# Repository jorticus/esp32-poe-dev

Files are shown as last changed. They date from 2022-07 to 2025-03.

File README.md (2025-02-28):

## ESP32 PoE Dev Board

A simple ESP32 ethernet + PoE dev board

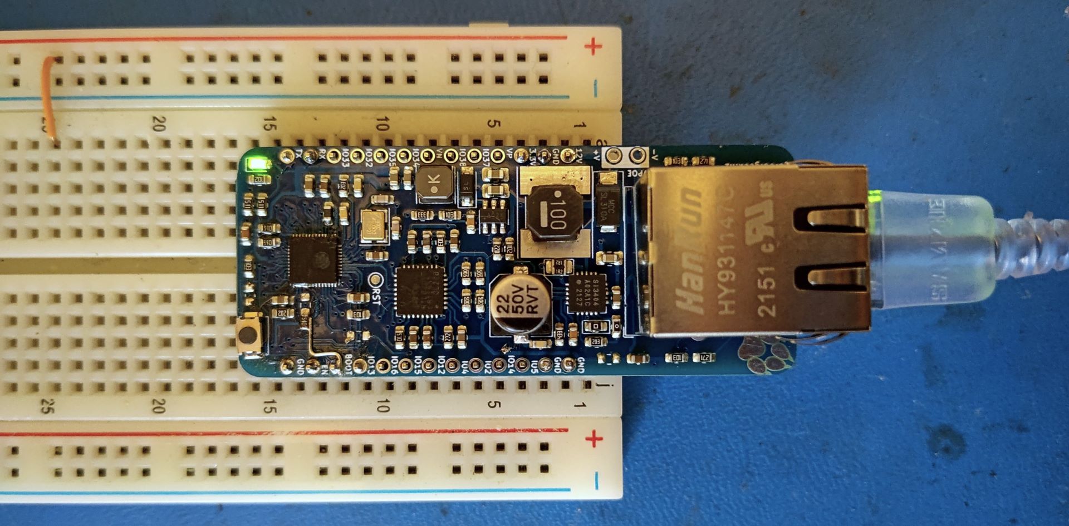
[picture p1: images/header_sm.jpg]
PoE Dev Board


WARNING: PoE is NOT ISOLATED! Be careful what you attach.

See [jared.geek.nz/esp32-poe-devboard](jared.geek.nz/esp32-poe-devboard) for the story.

## Usage

### ESPHome

```yaml
esp32:
  board: esp32dev

ethernet:
  type:     RTL8201
  mdc_pin:  GPIO23
  mdio_pin: GPIO18
  clk_mode: GPIO0_OUT
  phy_addr: 0

...
```

### Arduino

`main.cpp`
```cpp
void setup() {
    // WiFi antenna not available on this board
    WiFi.mode(WIFI_OFF); 

    ETH.begin();
    ETH.config();
}
```

`platformio.ini`
```ini
[platformio]

[env:esp32_poe]
platform  = espressif32
framework = arduino
board     = esp32_dev
build_flags = 
    -DETH_PHY_ADDR=0
    -DETH_PHY_MDC=23
    -DETH_PHY_MDIO=18
    -DETH_PHY_TYPE=ETH_PHY_RTL8201
    -DETH_CLK_MODE=ETH_CLOCK_GPIO0_OUT

```

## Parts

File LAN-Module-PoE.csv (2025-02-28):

Source: | P:\Electronics\LANModule\LAN-Module-PoE.kicad_sch
Date: | 4/12/2022 10:01:16 pm
Tool: | Eeschema (6.0.4)
Generator: | C:\Program Files\KiCad\6.0\bin\scripting\plugins/bom_csv_grouped_by_value.py
Component Count: | 102
Individual Components:
Item | Qty | Reference(s) | Value | LibPart | Footprint | Datasheet | Annotation | Dielectric | LCSC | Part | Part1 | Part2 | Range | Rating | Source | Spec | Tolerance
 |  | C1 | 100n | EspGateway-rescue:C_Small-device-EspGateway-rescue | Capacitor_SMD:C_0603_1608Metric |  |  |  | C113803 | CC0603KRX7R0BB104 |  |  | 100V |  |  | X5R
 |  | C2 | 100n | EspGateway-rescue:C_Small-device-EspGateway-rescue | Capacitor_SMD:C_0603_1608Metric
 |  | C3 | 100n | EspGateway-rescue:C_Small-device-EspGateway-rescue | Capacitor_SMD:C_0603_1608Metric |  |  |  |  |  |  |  | 50V |  |  | Y5V
 |  | C4 | 1u | EspGateway-rescue:C_Small-device-EspGateway-rescue | Capacitor_SMD:C_0805_2012Metric |  |  | X5R | C385977 | HMK212BC7105KGHTE |  |  | 100V
 |  | C5 | 10u | EspGateway-rescue:C_Small-device-EspGateway-rescue | Capacitor_SMD:C_0603_1608Metric |  |  |  |  |  |  |  | 3.3V
 |  | C6 | 1nF | EspGateway-rescue:C_Small-device-EspGateway-rescue | Capacitor_SMD:C_0603_1608Metric
 |  | C8 | 100n | EspGateway-rescue:C_Small-device-EspGateway-rescue | Resistor_SMD:R_0603_1608Metric
 |  | C9 | 100n | EspGateway-rescue:C_Small-device-EspGateway-rescue | Capacitor_SMD:C_0603_1608Metric
 |  | C10 | 1u | EspGateway-rescue:C_Small-device-EspGateway-rescue | Capacitor_SMD:C_0603_1608Metric |  |  |  |  |  |  |  | 3.3V
 |  | C11 | 1u | EspGateway-rescue:C_Small-device-EspGateway-rescue | Capacitor_SMD:C_0603_1608Metric |  |  |  |  |  |  |  | 3.3V
 |  | C12 | 22p | EspGateway-rescue:C_Small-device-EspGateway-rescue | Capacitor_SMD:C_0603_1608Metric
 |  | C13 | 22p | EspGateway-rescue:C_Small-device-EspGateway-rescue | Capacitor_SMD:C_0603_1608Metric
 |  | C14 | 4.7u | EspGateway-rescue:C_Small-device-EspGateway-rescue | Capacitor_SMD:C_0603_1608Metric |  |  |  |  |  |  |  | 3.3V
 |  | C15 | 3.3n | EspGateway-rescue:C_Small-device-EspGateway-rescue | Capacitor_SMD:C_0603_1608Metric
 |  | C16 | 10n | EspGateway-rescue:C_Small-device-EspGateway-rescue | Capacitor_SMD:C_0603_1608Metric
 |  | C17 | 100n | EspGateway-rescue:C_Small-device-EspGateway-rescue | Capacitor_SMD:C_0603_1608Metric |  |  |  |  |  |  |  | 12V |  |  | X5R
 |  | C18 | 2.2u | EspGateway-rescue:C_Small-device-EspGateway-rescue | Capacitor_SMD:C_0805_2012Metric |  |  | X5R | C268016 | UMK107BBJ225KA |  |  | 50V
 |  | C19 | 100n | EspGateway-rescue:C_Small-device-EspGateway-rescue | Capacitor_SMD:C_0603_1608Metric
 |  | C20 | 100n | EspGateway-rescue:C_Small-device-EspGateway-rescue | Capacitor_SMD:C_0603_1608Metric |  |  |  |  |  |  |  | 5V
 |  | C21 | 1u | EspGateway-rescue:C_Small-device-EspGateway-rescue | Capacitor_SMD:C_0603_1608Metric |  |  |  |  |  |  |  | 16V |  |  | X5R
 |  | C22 | 100n | EspGateway-rescue:C_Small-device-EspGateway-rescue | Resistor_SMD:R_0603_1608Metric |  |  |  |  |  |  |  |  |  |  | X5R
 |  | C23 | 100n | EspGateway-rescue:C_Small-device-EspGateway-rescue | Capacitor_SMD:C_0603_1608Metric |  |  |  |  |  |  |  |  |  |  | X5R
 |  | C24 | 100n | EspGateway-rescue:C_Small-device-EspGateway-rescue | Capacitor_SMD:C_0603_1608Metric |  |  |  |  |  |  |  |  |  |  | X5R
 |  | C25 | 100n | EspGateway-rescue:C_Small-device-EspGateway-rescue | Capacitor_SMD:C_0603_1608Metric |  |  |  |  |  |  |  |  |  |  | X5R
 |  | C26 | 100n | EspGateway-rescue:C_Small-device-EspGateway-rescue | Capacitor_SMD:C_0603_1608Metric |  |  |  |  |  |  |  |  |  |  | X5R
 |  | C27 | 22u | Device:C_Polarized_Small | Capacitor_SMD:C_Elec_6.3x5.4 | ~ |  |  | C487431 | VKMC1002A220MV |  |  | 100V
 |  | C29 | 2.2u | EspGateway-rescue:C_Small-device-EspGateway-rescue | Capacitor_SMD:C_0805_2012Metric |  |  | X5R | C268016 | UMK107BBJ225KA |  |  | 50V
 |  | D1 | SL310A | Device:D_Small | Diode_SMD:D_SMA | ~
 |  | D2 | PMEG6020ER,115 | Device:D_Small | Diode_SMD:D_SOD-123 | ~
 |  | D3 | Green | Device:LED_Small_Filled | LED_SMD:LED_0603_1608Metric | ~
 |  | J1 | HY931147C | Visclib:HY931147C | Connector_RJ:RJ45_Wuerth_7499111446_Horizontal |  |  |  | C12074 | LCSC:C12074 |  |  |  |  | https://lcsc.com/product-detail/Ethernet-Connectors-Modular-Connectors-RJ45-RJ11_HANRUN-Zhongshan-HanRun-Elec-HR911105A_C12074.html
 |  | J2 | ProtoCastellatedHeader | Visclib:ProtoCastellatedHeader | Visclib:ProtoHeader_65mil
 |  | J3 | ProtoCastellatedHeader | Visclib:ProtoCastellatedHeader | Visclib:ProtoHeader_65mil
 |  | J4 | ProtoCastellatedHeader | Visclib:ProtoCastellatedHeader | Visclib:ProtoHeader_65mil
 |  | J5 | ProtoCastellatedHeader | Visclib:ProtoCastellatedHeader | Visclib:ProtoHeader_65mil
 |  | J6 | ProtoCastellatedHeader | Visclib:ProtoCastellatedHeader | Visclib:ProtoHeader_65mil
 |  | J7 | ProtoCastellatedHeader | Visclib:ProtoCastellatedHeader | Visclib:ProtoHeader_65mil
 |  | J8 | ProtoCastellatedHeader | Visclib:ProtoCastellatedHeader | Visclib:ProtoHeader_65mil
 |  | J9 | ProtoCastellatedHeader | Visclib:ProtoCastellatedHeader | Visclib:ProtoHeader_65mil
 |  | J10 | ProtoCastellatedHeader | Visclib:ProtoCastellatedHeader | Visclib:ProtoHeader_65mil
 |  | J11 | ProtoCastellatedHeader | Visclib:ProtoCastellatedHeader | Visclib:ProtoHeader_65mil
 |  | J12 | ProtoCastellatedHeader | Visclib:ProtoCastellatedHeader | Visclib:ProtoHeader_65mil
 |  | J13 | ProtoCastellatedHeader | Visclib:ProtoCastellatedHeader | Visclib:ProtoHeader_65mil
 |  | J14 | ProtoCastellatedHeader | Visclib:ProtoCastellatedHeader | Visclib:ProtoHeader_65mil
 |  | J15 | ProtoCastellatedHeader | Visclib:ProtoCastellatedHeader | Visclib:ProtoHeader_65mil
 |  | J16 | ProtoCastellatedHeader | Visclib:ProtoCastellatedHeader | Visclib:ProtoHeader_65mil
 |  | J17 | ProtoCastellatedHeader | Visclib:ProtoCastellatedHeader | Visclib:ProtoHeader_65mil
 |  | J18 | ProtoCastellatedHeader | Visclib:ProtoCastellatedHeader | Visclib:ProtoHeader_65mil
 |  | J19 | ProtoCastellatedHeader | Visclib:ProtoCastellatedHeader | Visclib:ProtoHeader_65mil
 |  | J20 | ProtoCastellatedHeader | Visclib:ProtoCastellatedHeader | Visclib:ProtoHeader_65mil
 |  | J21 | ProtoCastellatedHeader | Visclib:ProtoCastellatedHeader | Visclib:ProtoHeader_65mil
 |  | J22 | ProtoCastellatedHeader | Visclib:ProtoCastellatedHeader | Visclib:ProtoHeader_65mil
 |  | J23 | ProtoCastellatedHeader | Visclib:ProtoCastellatedHeader | Visclib:ProtoHeader_65mil
 |  | J24 | ProtoCastellatedHeader | Visclib:ProtoCastellatedHeader | Visclib:ProtoHeader_65mil
 |  | J25 | ProtoCastellatedHeader | Visclib:ProtoCastellatedHeader | Visclib:ProtoHeader_65mil
 |  | J26 | ProtoCastellatedHeader | Visclib:ProtoCastellatedHeader | Visclib:ProtoHeader_65mil
 |  | J27 | ProtoCastellatedHeader | Visclib:ProtoCastellatedHeader | Visclib:ProtoHeader_65mil
 |  | J28 | ProtoCastellatedHeader | Visclib:ProtoCastellatedHeader | Visclib:ProtoHeader_65mil
 |  | J29 | ProtoCastellatedHeader | Visclib:ProtoCastellatedHeader | Visclib:ProtoHeader_65mil
 |  | L1 | FB 600R@100MHz 1.3A | EspGateway-rescue:L_Small-device-EspGateway-rescue | Resistor_SMD:R_0603_1608Metric |  |  |  | C85833 | BLM18KG601SN1D
 |  | L2 | 10uH 1A | Device:L_Small | Inductor_SMD:L_Taiyo-Yuden_NR-40xx | ~ |  |  | C222882 | NRS4018T100MDGJ
 |  | L3 | FB 600R@100MHz 1.3A | EspGateway-rescue:L_Small-device-EspGateway-rescue | Resistor_SMD:R_0603_1608Metric |  |  |  | C85833 | BLM18KG601SN1D
 |  | L4 | 33uH | Device:L_Small | Inductor_SMD:L_Taiyo-Yuden_NR-80xx_HandSoldering | ~ |  |  | C2681905 | YNR8065-330M |  |  |  | 1.2A
 |  | LOGO1 | Logo | Visclib:Logo | Visclib:wolfpaw-0.3
 |  | R1 | 10k | EspGateway-rescue:R_Small_US-device-EspGateway-rescue | Resistor_SMD:R_0603_1608Metric
 |  | R2 | 2k | EspGateway-rescue:R_Small_US-device-EspGateway-rescue | Resistor_SMD:R_0603_1608Metric
 |  | R3 | 20K | EspGateway-rescue:R_Small_US-device-EspGateway-rescue | Resistor_SMD:R_0603_1608Metric
 |  | R4 | 499R | EspGateway-rescue:R_Small_US-device-EspGateway-rescue | Resistor_SMD:R_0603_1608Metric
 |  | R6 | 24.3k 1% | EspGateway-rescue:R_Small_US-device-EspGateway-rescue | Resistor_SMD:R_0603_1608Metric |  |  |  | C2930079
 |  | R7 | DNP | EspGateway-rescue:R_Small_US-device-EspGateway-rescue | Resistor_SMD:R_0603_1608Metric
 |  | R8 | 2.49k 1% | EspGateway-rescue:R_Small_US-device-EspGateway-rescue | Resistor_SMD:R_0603_1608Metric |  |  |  | C2930072
 |  | R9 | 10k | EspGateway-rescue:R_Small_US-device-EspGateway-rescue | Resistor_SMD:R_0603_1608Metric
 |  | R10 | 10k | EspGateway-rescue:R_Small_US-device-EspGateway-rescue | Resistor_SMD:R_0603_1608Metric
 |  | R11 | 10k | EspGateway-rescue:R_Small_US-device-EspGateway-rescue | Resistor_SMD:R_0603_1608Metric
 |  | R12 | 10k | EspGateway-rescue:R_Small_US-device-EspGateway-rescue | Resistor_SMD:R_0603_1608Metric
 |  | R13 | 50R 1% | EspGateway-rescue:R_Small_US-device-EspGateway-rescue | Resistor_SMD:R_0603_1608Metric |  |  |  | C2759402 |  |  |  |  |  |  |  | 1%
 |  | R14 | 50R 1% | EspGateway-rescue:R_Small_US-device-EspGateway-rescue | Resistor_SMD:R_0603_1608Metric |  |  |  |  |  |  |  |  |  |  |  | 1%
 |  | R15 | 240R | EspGateway-rescue:R_Small_US-device-EspGateway-rescue | Resistor_SMD:R_0603_1608Metric
 |  | R16 | 240R | EspGateway-rescue:R_Small_US-device-EspGateway-rescue | Resistor_SMD:R_0603_1608Metric
 |  | R17 | 50R 1% | EspGateway-rescue:R_Small_US-device-EspGateway-rescue | Resistor_SMD:R_0603_1608Metric |  |  |  |  |  |  |  |  |  |  |  | 1%
 |  | R18 | 50R 1% | EspGateway-rescue:R_Small_US-device-EspGateway-rescue | Resistor_SMD:R_0603_1608Metric |  |  |  |  |  |  |  |  |  |  | Tolerance
 |  | R19 | 0R | EspGateway-rescue:R_Small_US-device-EspGateway-rescue | Resistor_SMD:R_0603_1608Metric
 |  | R20 | 0.62R | EspGateway-rescue:R_Small_US-device-EspGateway-rescue | Resistor_SMD:R_0805_2012Metric |  |  |  | C2930222 |  |  |  |  |  |  | 1/10W
 |  | R21 | 47k | EspGateway-rescue:R_Small_US-device-EspGateway-rescue | Resistor_SMD:R_0603_1608Metric
 |  | R22 | 499R | EspGateway-rescue:R_Small_US-device-EspGateway-rescue | Resistor_SMD:R_0603_1608Metric
 |  | R23 | 1k | EspGateway-rescue:R_Small_US-device-EspGateway-rescue | Resistor_SMD:R_0603_1608Metric
 |  | R24 | 8.2k | EspGateway-rescue:R_Small_US-device-EspGateway-rescue | Resistor_SMD:R_0603_1608Metric
 |  | R25 | 0R | EspGateway-rescue:R_Small_US-device-EspGateway-rescue | Resistor_SMD:R_0603_1608Metric |  | DNP
 |  | R26 | 33k 1% | EspGateway-rescue:R_Small_US-device-EspGateway-rescue | Resistor_SMD:R_0603_1608Metric
 |  | R27 | 10k 1% | EspGateway-rescue:R_Small_US-device-EspGateway-rescue | Resistor_SMD:R_0603_1608Metric
 |  | R28 | 1k | EspGateway-rescue:R_Small_US-device-EspGateway-rescue | Resistor_SMD:R_0603_1608Metric
 |  | R29 | 50R | EspGateway-rescue:R_Small_US-device-EspGateway-rescue | Resistor_SMD:R_0603_1608Metric
 |  | R30 | 50R | EspGateway-rescue:R_Small_US-device-EspGateway-rescue | Resistor_SMD:R_0603_1608Metric
 |  | R31 | 50R | EspGateway-rescue:R_Small_US-device-EspGateway-rescue | Resistor_SMD:R_0603_1608Metric
 |  | R32 | 50R | EspGateway-rescue:R_Small_US-device-EspGateway-rescue | Resistor_SMD:R_0603_1608Metric
 |  | SW1 | RESET | Switch:SW_Push | Button_Switch_SMD:SW_Push_SPST_NO_Alps_SKRK | ~
 |  | TP1 | TP | visclib:TP | Visclib:TP-1MM
 |  | U1 | ESP32-U4WDH | Visclib:ESP32-D0WD | Package_DFN_QFN:QFN-48-1EP_5x5mm_P0.35mm_EP3.7x3.7mm_ThermalVias |  |  |  | C529586/C3013932 |  | LCSC:C529586 | LCSC:C967021
 |  | U2 | Si3404 | Visclib:Si3404 | Package_DFN_QFN:QFN-20-1EP_4x4mm_P0.5mm_EP2.6x2.6mm |  |  |  | C461934 | LCSC:C461934
 |  | U3 | LV2842XLVDDCR | Visclib:LV2841 | Package_TO_SOT_SMD:SOT-23-6 |  |  |  | C225807
 |  | U4 | RTL8201F | EspGateway-rescue:RTL8201F-visclib-EspGateway-rescue | Package_DFN_QFN:QFN-32-1EP_5x5mm_P0.5mm_EP3.1x3.1mm |  |  |  | C2763557/C45044 |  |  |  |  |  | https://lcsc.com/product-detail/Ethernet-ICs_Realtek-Semicon-RTL8201FI-VC-CG_C2763557.html
 |  | Y1 | 40MHz | EspGateway-rescue:Crystal_GND24_Small-device-EspGateway-rescue | Crystal:Crystal_SMD_3225-4Pin_3.2x2.5mm |  |  |  | C9010/C555624 |  |  |  |  |  |  | ±10ppm
Collated Components:
Item | Qty | Reference(s) | Value | LibPart | Footprint | Datasheet | Annotation | Dielectric | LCSC | Part | Part1 | Part2 | Range | Rating | Source | Spec | Tolerance
1 | 11 | C1, C2, C3, C9, C17, C19, C20, C23, C24, C25, C26 | 100n | EspGateway-rescue:C_Small-device-EspGateway-rescue | Capacitor_SMD:C_0603_1608Metric |  |  |  | C113803 | CC0603KRX7R0BB104 |  |  | 100V |  |  | X5R
2 | 1 | C4 | 1u | EspGateway-rescue:C_Small-device-EspGateway-rescue | Capacitor_SMD:C_0805_2012Metric |  |  | X5R | C385977 | HMK212BC7105KGHTE |  |  | 100V
3 | 1 | C5 | 10u | EspGateway-rescue:C_Small-device-EspGateway-rescue | Capacitor_SMD:C_0603_1608Metric |  |  |  |  |  |  |  | 3.3V
4 | 1 | C6 | 1nF | EspGateway-rescue:C_Small-device-EspGateway-rescue | Capacitor_SMD:C_0603_1608Metric
5 | 2 | C8, C22 | 100n | EspGateway-rescue:C_Small-device-EspGateway-rescue | Resistor_SMD:R_0603_1608Metric |  |  |  |  |  |  |  |  |  |  | X5R
6 | 3 | C10, C11, C21 | 1u | EspGateway-rescue:C_Small-device-EspGateway-rescue | Capacitor_SMD:C_0603_1608Metric |  |  |  |  |  |  |  | 3.3V |  |  | X5R
7 | 2 | C12, C13 | 22p | EspGateway-rescue:C_Small-device-EspGateway-rescue | Capacitor_SMD:C_0603_1608Metric
8 | 1 | C14 | 4.7u | EspGateway-rescue:C_Small-device-EspGateway-rescue | Capacitor_SMD:C_0603_1608Metric |  |  |  |  |  |  |  | 3.3V
9 | 1 | C15 | 3.3n | EspGateway-rescue:C_Small-device-EspGateway-rescue | Capacitor_SMD:C_0603_1608Metric
10 | 1 | C16 | 10n | EspGateway-rescue:C_Small-device-EspGateway-rescue | Capacitor_SMD:C_0603_1608Metric
11 | 2 | C18, C29 | 2.2u | EspGateway-rescue:C_Small-device-EspGateway-rescue | Capacitor_SMD:C_0805_2012Metric |  |  | X5R | C268016 | UMK107BBJ225KA |  |  | 50V
12 | 1 | C27 | 22u | Device:C_Polarized_Small | Capacitor_SMD:C_Elec_6.3x5.4 | ~ |  |  | C487431 | VKMC1002A220MV |  |  | 100V
13 | 1 | D1 | SL310A | Device:D_Small | Diode_SMD:D_SMA | ~
14 | 1 | D2 | PMEG6020ER,115 | Device:D_Small | Diode_SMD:D_SOD-123 | ~
15 | 1 | D3 | Green | Device:LED_Small_Filled | LED_SMD:LED_0603_1608Metric | ~
16 | 1 | J1 | HY931147C | Visclib:HY931147C | Connector_RJ:RJ45_Wuerth_7499111446_Horizontal |  |  |  | C12074 | LCSC:C12074 |  |  |  |  | https://lcsc.com/product-detail/Ethernet-Connectors-Modular-Connectors-RJ45-RJ11_HANRUN-Zhongshan-HanRun-Elec-HR911105A_C12074.html
17 | 28 | J2, J3, J4, J5, J6, J7, J8, J9, J10, J11, J12, J13, J14, J15, J16, J17, J18, J19, J20, J21, J22, J23, J24, J25, J26, J27, J28, J29 | ProtoCastellatedHeader | Visclib:ProtoCastellatedHeader | Visclib:ProtoHeader_65mil
18 | 2 | L1, L3 | FB 600R@100MHz 1.3A | EspGateway-rescue:L_Small-device-EspGateway-rescue | Resistor_SMD:R_0603_1608Metric |  |  |  | C85833 | BLM18KG601SN1D
19 | 1 | L2 | 10uH 1A | Device:L_Small | Inductor_SMD:L_Taiyo-Yuden_NR-40xx | ~ |  |  | C222882 | NRS4018T100MDGJ
20 | 1 | L4 | 33uH | Device:L_Small | Inductor_SMD:L_Taiyo-Yuden_NR-80xx_HandSoldering | ~ |  |  | C2681905 | YNR8065-330M |  |  |  | 1.2A
21 | 1 | LOGO1 | Logo | Visclib:Logo | Visclib:wolfpaw-0.3
22 | 5 | R1, R9, R10, R11, R12 | 10k | EspGateway-rescue:R_Small_US-device-EspGateway-rescue | Resistor_SMD:R_0603_1608Metric
23 | 1 | R2 | 2k | EspGateway-rescue:R_Small_US-device-EspGateway-rescue | Resistor_SMD:R_0603_1608Metric
24 | 1 | R3 | 20K | EspGateway-rescue:R_Small_US-device-EspGateway-rescue | Resistor_SMD:R_0603_1608Metric
25 | 2 | R4, R22 | 499R | EspGateway-rescue:R_Small_US-device-EspGateway-rescue | Resistor_SMD:R_0603_1608Metric
26 | 1 | R6 | 24.3k 1% | EspGateway-rescue:R_Small_US-device-EspGateway-rescue | Resistor_SMD:R_0603_1608Metric |  |  |  | C2930079
27 | 1 | R7 | DNP | EspGateway-rescue:R_Small_US-device-EspGateway-rescue | Resistor_SMD:R_0603_1608Metric
28 | 1 | R8 | 2.49k 1% | EspGateway-rescue:R_Small_US-device-EspGateway-rescue | Resistor_SMD:R_0603_1608Metric |  |  |  | C2930072
29 | 4 | R13, R14, R17, R18 | 50R 1% | EspGateway-rescue:R_Small_US-device-EspGateway-rescue | Resistor_SMD:R_0603_1608Metric |  |  |  | C2759402 |  |  |  |  |  |  | Tolerance | 1%
30 | 2 | R15, R16 | 240R | EspGateway-rescue:R_Small_US-device-EspGateway-rescue | Resistor_SMD:R_0603_1608Metric
31 | 2 | R19, R25 | 0R | EspGateway-rescue:R_Small_US-device-EspGateway-rescue | Resistor_SMD:R_0603_1608Metric |  | DNP
32 | 1 | R20 | 0.62R | EspGateway-rescue:R_Small_US-device-EspGateway-rescue | Resistor_SMD:R_0805_2012Metric |  |  |  | C2930222 |  |  |  |  |  |  | 1/10W
33 | 1 | R21 | 47k | EspGateway-rescue:R_Small_US-device-EspGateway-rescue | Resistor_SMD:R_0603_1608Metric
34 | 2 | R23, R28 | 1k | EspGateway-rescue:R_Small_US-device-EspGateway-rescue | Resistor_SMD:R_0603_1608Metric
35 | 1 | R24 | 8.2k | EspGateway-rescue:R_Small_US-device-EspGateway-rescue | Resistor_SMD:R_0603_1608Metric
36 | 1 | R26 | 33k 1% | EspGateway-rescue:R_Small_US-device-EspGateway-rescue | Resistor_SMD:R_0603_1608Metric
37 | 1 | R27 | 10k 1% | EspGateway-rescue:R_Small_US-device-EspGateway-rescue | Resistor_SMD:R_0603_1608Metric
38 | 4 | R29, R30, R31, R32 | 50R | EspGateway-rescue:R_Small_US-device-EspGateway-rescue | Resistor_SMD:R_0603_1608Metric
39 | 1 | SW1 | RESET | Switch:SW_Push | Button_Switch_SMD:SW_Push_SPST_NO_Alps_SKRK | ~
40 | 1 | TP1 | TP | visclib:TP | Visclib:TP-1MM
41 | 1 | U1 | ESP32-U4WDH | Visclib:ESP32-D0WD | Package_DFN_QFN:QFN-48-1EP_5x5mm_P0.35mm_EP3.7x3.7mm_ThermalVias |  |  |  | C529586/C3013932 |  | LCSC:C529586 | LCSC:C967021
42 | 1 | U2 | Si3404 | Visclib:Si3404 | Package_DFN_QFN:QFN-20-1EP_4x4mm_P0.5mm_EP2.6x2.6mm |  |  |  | C461934 | LCSC:C461934
43 | 1 | U3 | LV2842XLVDDCR | Visclib:LV2841 | Package_TO_SOT_SMD:SOT-23-6 |  |  |  | C225807
44 | 1 | U4 | RTL8201F | EspGateway-rescue:RTL8201F-visclib-EspGateway-rescue | Package_DFN_QFN:QFN-32-1EP_5x5mm_P0.5mm_EP3.1x3.1mm |  |  |  | C2763557/C45044 |  |  |  |  |  | https://lcsc.com/product-detail/Ethernet-ICs_Realtek-Semicon-RTL8201FI-VC-CG_C2763557.html
45 | 1 | Y1 | 40MHz | EspGateway-rescue:Crystal_GND24_Small-device-EspGateway-rescue | Crystal:Crystal_SMD_3225-4Pin_3.2x2.5mm |  |  |  | C9010/C555624 |  |  |  |  |  |  | ±10ppm

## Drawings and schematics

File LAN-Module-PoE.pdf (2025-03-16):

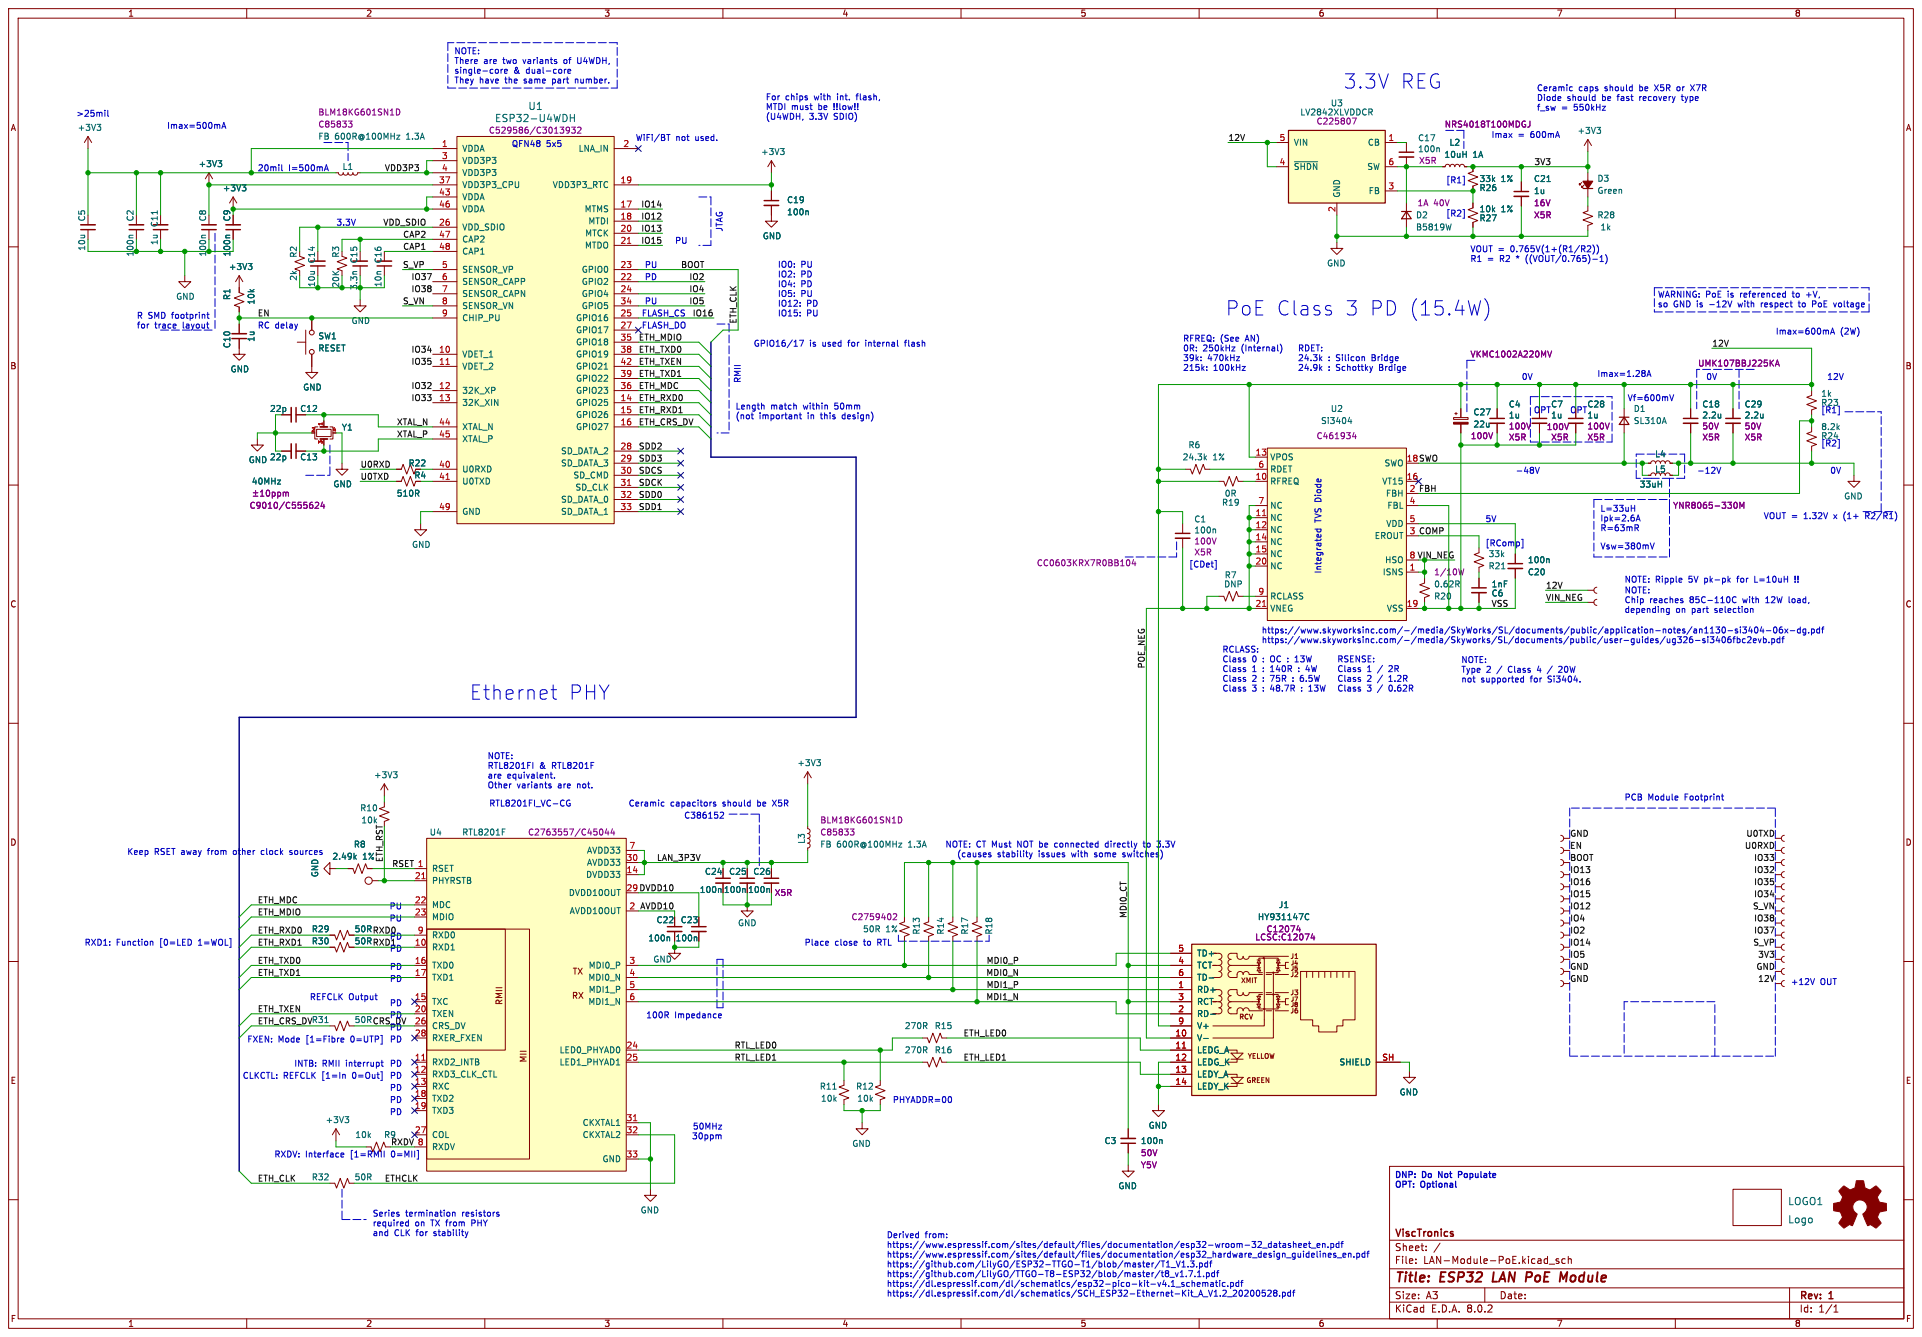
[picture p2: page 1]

Diode should be fast recovery type
f_sw = 550kHz

For chips with int. flash, MTDI must be !!low!! (U4WDH, 3.3V SDIO)

Place close to RTL RMII

VOUT = 1.32V x (1+ R2/R1) 0V RC delay R SMD footprint
for trace layout

https://www.skyworksinc.com/-/media/Skyworks/SL/documents/public/user-guides/ug326-si3406fbc2evb.pdf Integrated TVS Diode

https://www.skyworksinc.com/-/media/SkyWorks/SL/documents/public/application-notes/an1130-si3404-06x-dg.pdf

DNP: Do Not Populate OPT: Optional REFCLK Output

and CLK for stability

Derived from: https://www.espressif.com/sites/default/files/documentation/esp32-wroom-32_datasheet_en.pdf

https://www.espressif.com/sites/default/files/documentation/esp32_hardware_design_guidelines_en.pdf
https://github.com/LilyGO/ESP32-TTGO-T1/blob/master/T1_V1.3.pdf
https://github.com/LilyGO/TTGO-T8-ESP32/blob/master/t8_v1.7.1.pdf
https://dl.espressif.com/dl/schematics/esp32-pico-kit-v4.1_schematic.pdf
https://dl.espressif.com/dl/schematics/SCH_ESP32-Ethernet-Kit_A_V1.2_20200528.pdf

Id: 1/1 Title: ESP32 LAN PoE Module

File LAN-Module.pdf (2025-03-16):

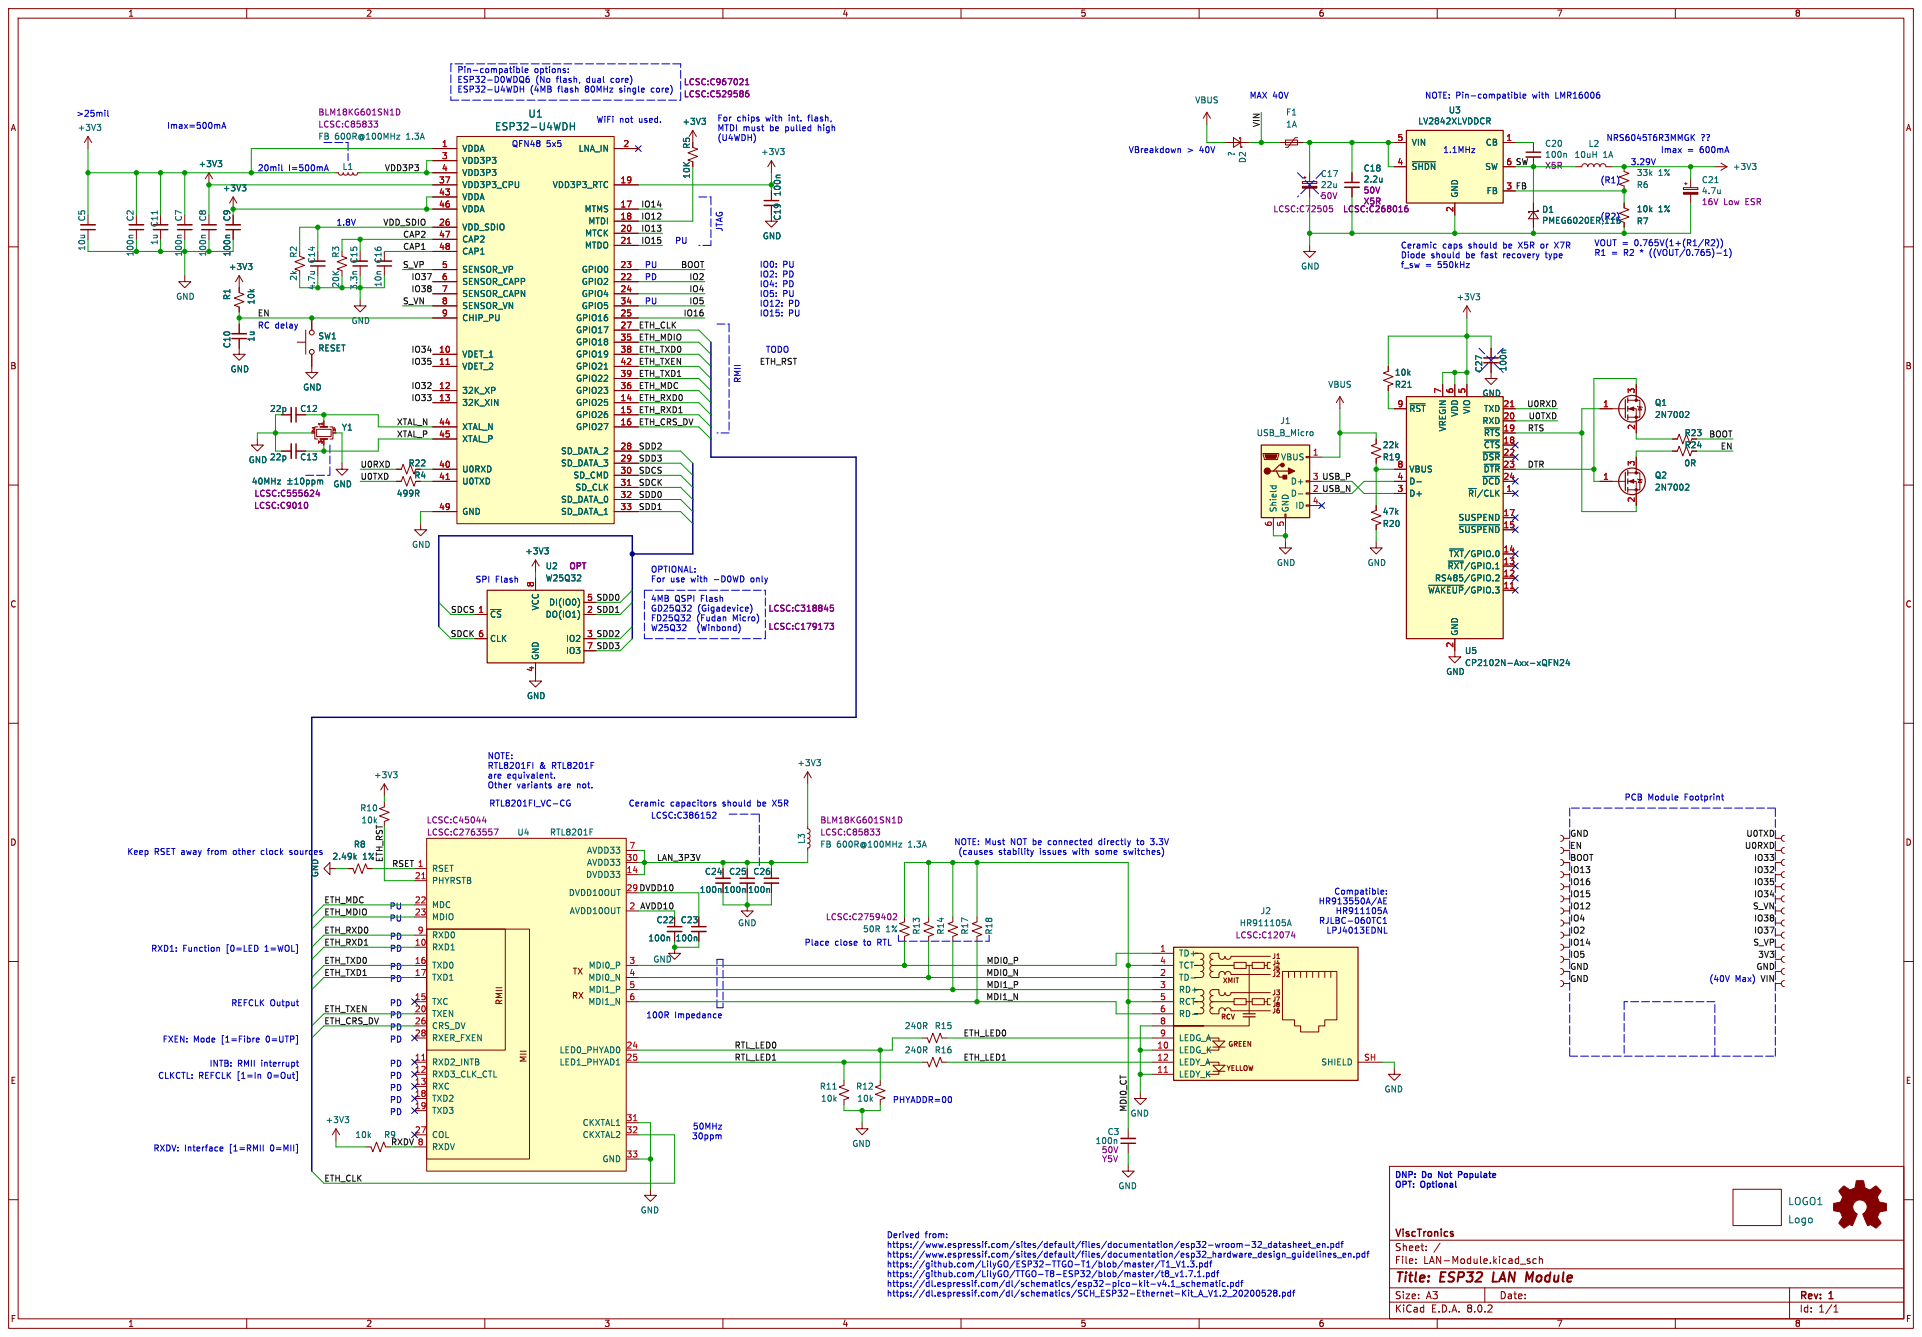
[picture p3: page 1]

For chips with int. flash, MTDI must be pulled high

2 FB 3 ~{SHDN} 4 VIN 5 SW 6 U3
LV2842XLVDDCR

2 FB 3 ~{SHDN} 4 VIN 5 SW 6 R7

Ceramic caps should be X5R or X7R
Diode should be fast recovery type
f_sw = 550kHz

2 RXD 20 TXD 21 ~{DSR} 22 ~{DTR} 23 ~{DCD} 24 D+ 3 D- 4 VIO

DNP: Do Not Populate OPT: Optional 50MHz 30ppm

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

Id: 1/1 Title: ESP32 LAN Module

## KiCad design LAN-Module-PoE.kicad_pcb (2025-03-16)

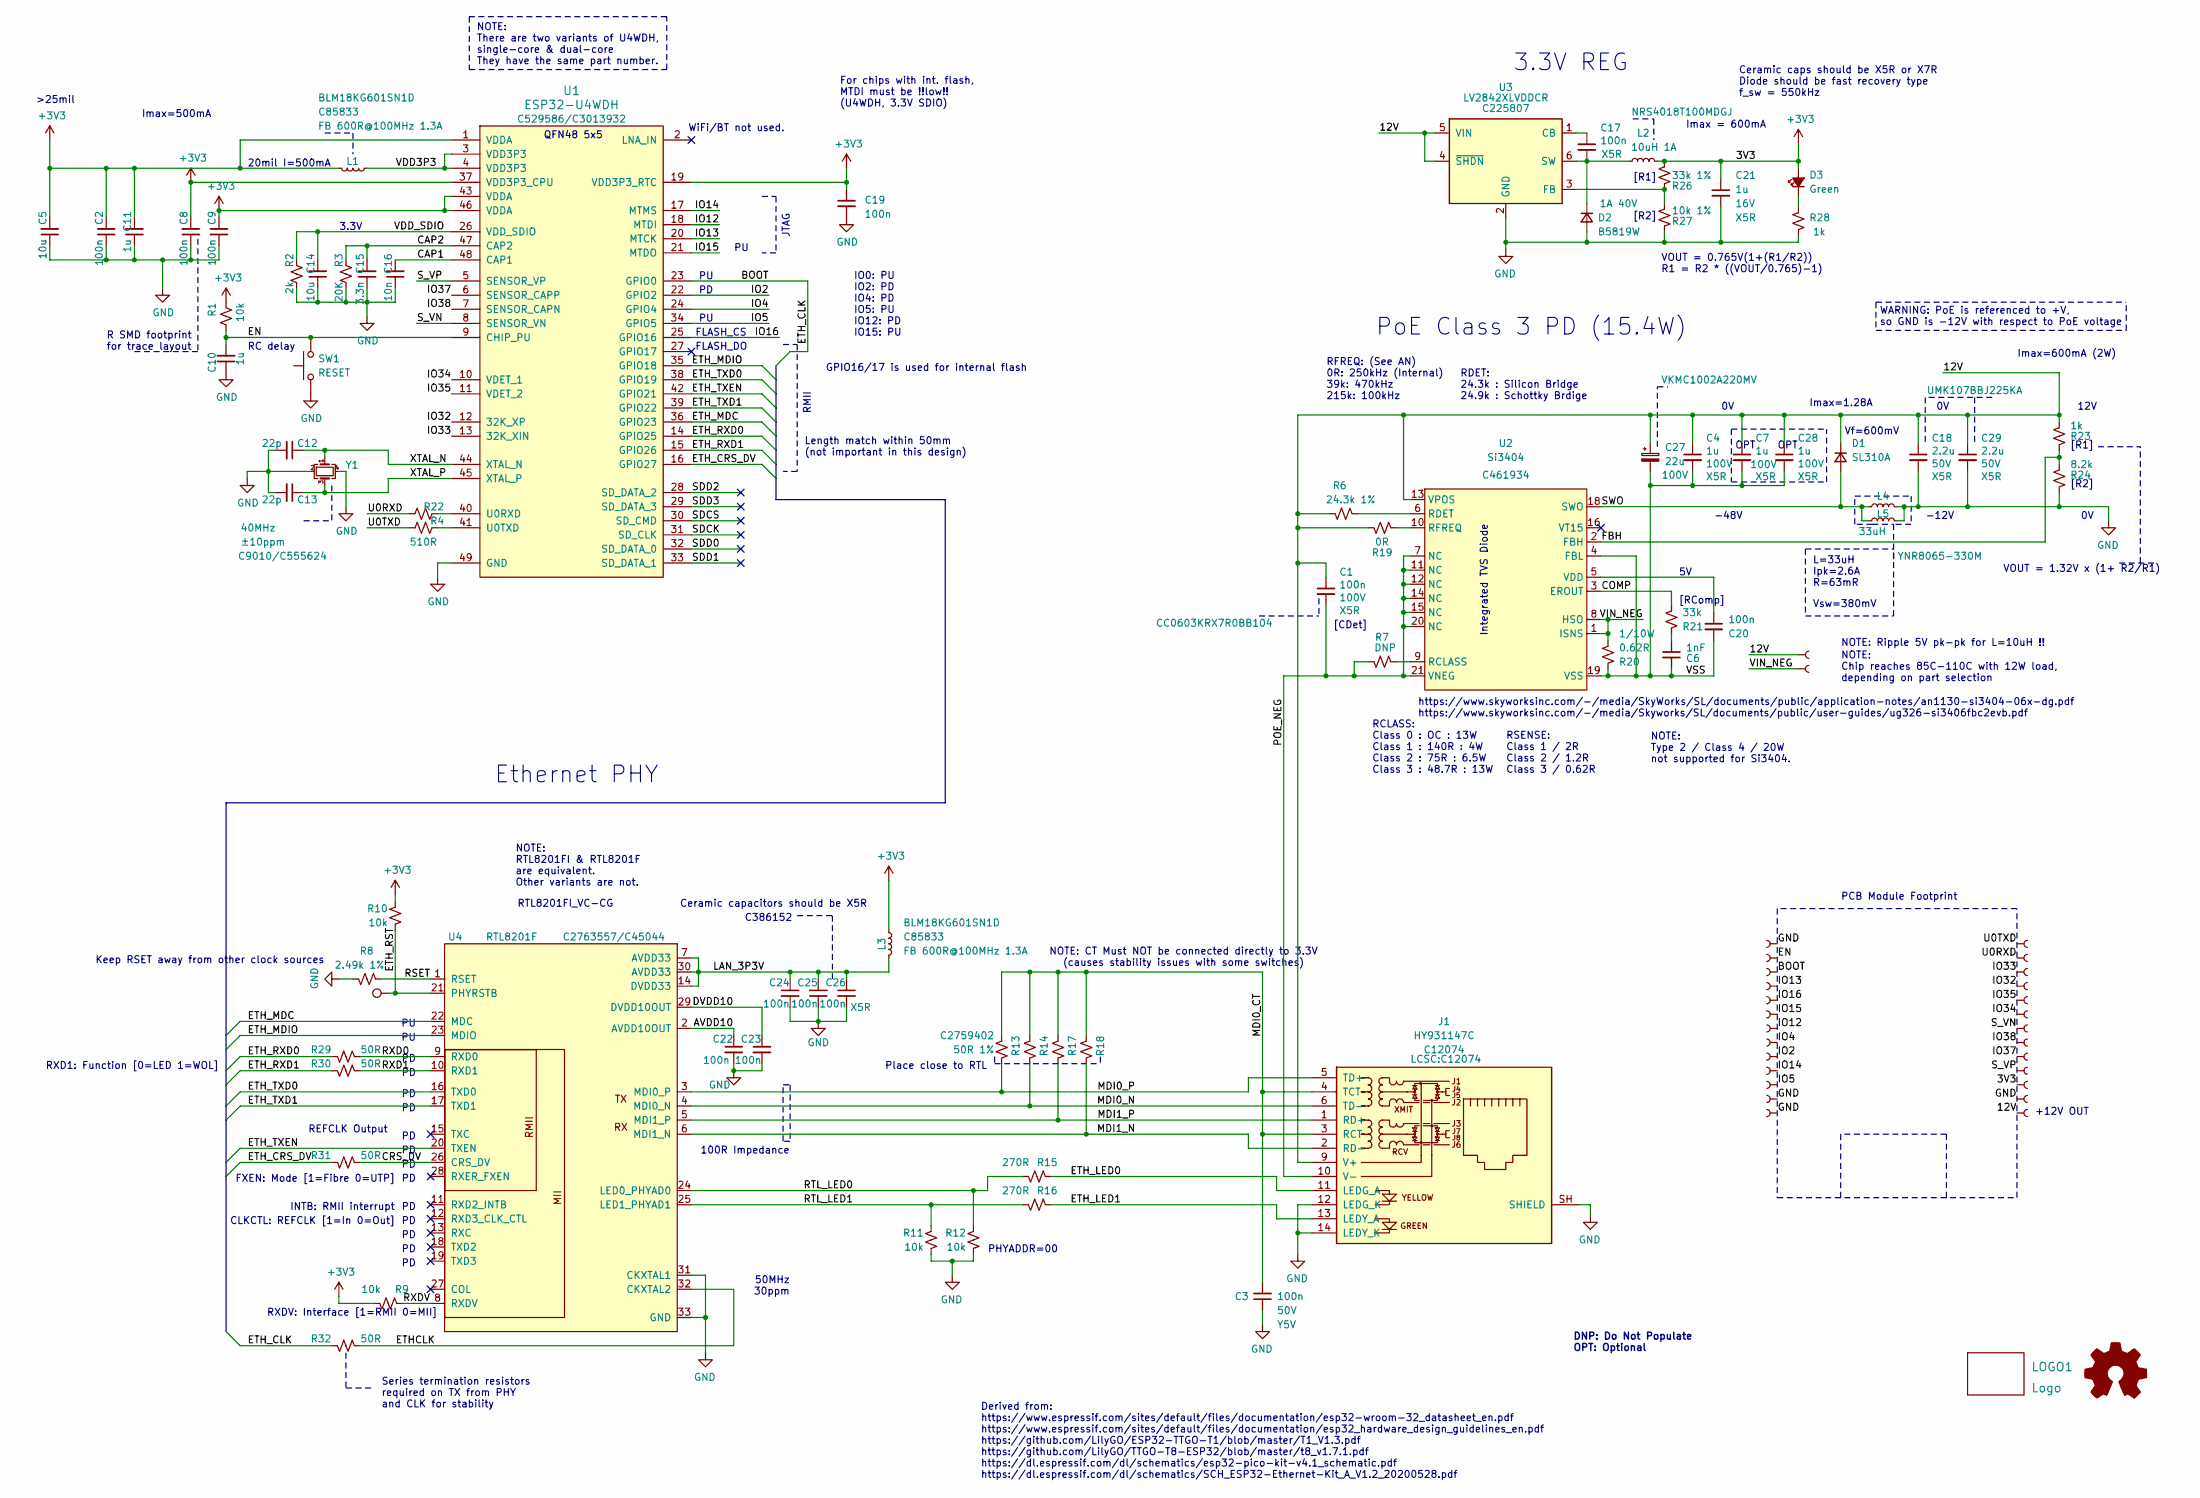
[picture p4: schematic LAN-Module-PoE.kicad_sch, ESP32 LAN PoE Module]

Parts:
C1: 100n; C_0603_1608Metric; Part CC0603KRX7R0BB104; LCSC C113803
C2, C3, C9, C17, C19, C20, C23, C24, C25, C26: 100n; C_0603_1608Metric
C4: 1u; C_0805_2012Metric; Part HMK212BC7105KGHTE; LCSC C385977
C5, C14: 10u; C_0603_1608Metric
C6: 1nF; C_0603_1608Metric
C7, C10, C11, C21, C28: 1u; C_0603_1608Metric
C8, C22: 100n; R_0603_1608Metric
C12, C13: 22p; C_0603_1608Metric
C15: 3.3n; C_0603_1608Metric
C16: 10n; C_0603_1608Metric
C18, C29: 2.2u; C_0805_2012Metric; Part UMK107BBJ225KA; LCSC C268016
C27: 22u; C_Elec_6.3x5.4; Part VKMC1002A220MV; LCSC C487431
D1: SL310A; D_SMA
D2: B5819W; D_SOD-123; Rating 1A 40V; LCSC C2685454
D3: Green; LED_0603_1608Metric
J1: HY931147C; RJ45_Wuerth_7499111446_Horizontal; Part LCSC:C12074; LCSC C12074
J2, J3, J4, J5, J6, J7, J8, J9, J10, J11, J12, J13, J14, J15, J16, J17, J18, J19, J20, J21, J22, J23, J24, J25, J26, J27, J28, J29: ProtoCastellatedHeader; ProtoHeader_65mil
L1, L3: FB 600R@100MHz 1.3A; R_0603_1608Metric; Part BLM18KG601SN1D; LCSC C85833
L2: 10uH 1A; L_Taiyo-Yuden_NR-40xx; Part NRS4018T100MDGJ; LCSC C222882
L4: 33uH; L_Taiyo-Yuden_NR-80xx_HandSoldering; Rating 1.2A; Part YNR8065-330M; LCSC C2681905
L5: -; L_Taiyo-Yuden_NR-60xx
LOGO1: Logo; wolfpaw-0.3
R1, R9, R10, R11, R12: 10k; R_0603_1608Metric
R2: 2k; R_0603_1608Metric
R3: 20K; R_0603_1608Metric
R4, R22: 510R; R_0603_1608Metric
R6: 24.3k 1%; R_0603_1608Metric; LCSC C2930079
R7: DNP; R_0603_1608Metric
R8: 2.49k 1%; R_0603_1608Metric; LCSC C2930072
R13: 50R 1%; R_0603_1608Metric; Tolerance 1%; LCSC C2759402
R14, R17: 50R 1%; R_0603_1608Metric; Tolerance 1%
R15, R16: 270R; R_0603_1608Metric
R18: 50R 1%; R_0603_1608Metric
R19: 0R; R_0603_1608Metric
R20: 0.62R; R_0805_2012Metric; LCSC C2930222
R21: 33k; R_0603_1608Metric
R23: 1k; R_0603_1608Metric; LCSC C22548
R24: 8.2k; R_0603_1608Metric; LCSC C114637
R26: 33k 1%; R_0603_1608Metric; LCSC C126359
R27: 10k 1%; R_0603_1608Metric; LCSC C98220
R28: 1k; R_0603_1608Metric
R29, R30, R31, R32: 50R; R_0603_1608Metric
SW1: RESET; SW_Push_SPST_NO_Alps_SKRK
TP1: TP; TP-1MM
U1: ESP32-U4WDH; QFN-48-1EP_5x5mm_P0.35mm_EP3.7x3.7mm_ThermalVias; LCSC C529586/C3013932
U2: Si3404; QFN-20-1EP_4x4mm_P0.5mm_EP2.6x2.6mm; LCSC C461934
U3: LV2842XLVDDCR; SOT-23-6; LCSC C225807
U4: RTL8201F; QFN-32-1EP_5x5mm_P0.5mm_EP3.1x3.1mm; LCSC C2763557/C45044
Y1: 40MHz; Crystal_SMD_3225-4Pin_3.2x2.5mm; LCSC C9010/C555624

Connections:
+3V3: C2.2, C5.2, C8.2, C9.2, C11.2, C19.1, C21.1, D3.2 (A), J15.1, L1.2, L2.2, L3.1, R1.2, R9.1, R10.1, R26.2, U1.1 (VDDA), U1.19 (VDD3P3_RTC), U1.37 (VDD3P3_CPU), U1.43 (VDDA), U1.46 (VDDA)
/12V: C1.1, C4.1, C7.1, C18.1, C27.1, C28.1, C29.1, D1.1 (K), J1.9 (V+), J2.1, J28.1, R6.1, R19.1, R23.2, U2.13 (VPOS), U3.4 (~SHDN), U3.5 (VIN)
/AVDD10: C22.1, U4.2 (AVDD10OUT)
/BOOT: J5.1, R32.1, U1.23 (GPIO0)
/CAP1: C16.2, U1.48 (CAP1)
/CAP2: C15.2, R3.2, U1.47 (CAP2)
/COMP: R21.2, U2.3 (EROUT)
/CRS_DV: R31.2, U4.26 (CRS_DV)
/DVDD10: C23.1, U4.29 (DVDD10OUT)
/EN: C10.2, J4.1, R1.1, SW1.2, U1.9 (CHIP_PU)
/ETHCLK: R32.2, U4.32 (CKXTAL2)
/ETH_CRS_DV: R31.1, U1.16 (GPIO27)
/ETH_LED0: J1.11 (LEDG_A), R15.2
/ETH_LED1: J1.13 (LEDY_A), R16.2
/ETH_MDC: U1.36 (GPIO23), U4.22 (MDC)
/ETH_MDIO: U1.35 (GPIO18), U4.23 (MDIO)
/ETH_RST: R10.2, TP1.1, U4.21 (PHYRSTB)
/ETH_RXD0: R29.1, U1.14 (GPIO25)
/ETH_RXD1: R30.1, U1.15 (GPIO26)
/ETH_TXD0: U1.38 (GPIO19), U4.16 (TXD0)
/ETH_TXD1: U1.39 (GPIO22), U4.17 (TXD1)
/ETH_TXEN: U1.42 (GPIO21), U4.20 (TXEN)
/FBH: R23.1, R24.2, U2.2 (FBH)
/IO2: J11.1, U1.22 (GPIO2)
/IO4: J10.1, U1.24 (GPIO4)
/IO5: J13.1, U1.34 (GPIO5)
/IO12: J9.1, U1.18 (MTDI)
/IO13: J6.1, U1.20 (MTCK)
/IO14: J12.1, U1.17 (MTMS)
/IO15: J8.1, U1.21 (MTDO)
/IO16: J7.1, U1.25 (GPIO16)
/IO32: J20.1, U1.12 (32K_XP)
/IO33: J19.1, U1.13 (32K_XIN)
/IO34: J22.1, U1.10 (VDET_1)
/IO35: J21.1, U1.11 (VDET_2)
/IO37: J25.1, U1.6 (SENSOR_CAPP)
/IO38: J24.1, U1.7 (SENSOR_CAPN)
/LAN_3P3V: C24.1, C25.1, C26.1, L3.2, U4.7 (AVDD33), U4.14 (DVDD33), U4.30 (AVDD33)
/MDI0_CT: C3.2, J1.3 (RCT), J1.4 (TCT), R13.1, R14.1, R17.1, R18.1
/MDI0_N: J1.6 (TD-), R14.2, U4.4 (MDI0_N)
/MDI0_P: J1.5 (TD+), R13.2, U4.3 (MDI0_P)
/MDI1_N: J1.2 (RD-), R18.2, U4.6 (MDI1_N)
/MDI1_P: J1.1 (RD+), R17.2, U4.5 (MDI1_P)
/POE_NEG: C1.2, J1.10 (V-), R7.1, U2.7 (NC), U2.11 (NC), U2.12 (NC), U2.14 (NC), U2.15 (NC), U2.20 (NC), U2.21 (VNEG)
/RSET: R8.2, U4.1 (RSET)
/RTL_LED0: R12.1, R15.1, U4.24 (LED0_PHYAD0)
/RTL_LED1: R11.1, R16.1, U4.25 (LED1_PHYAD1)
/RXD0: R29.2, U4.9 (RXD0)
/RXD1: R30.2, U4.10 (RXD1)
/RXDV: R9.2, U4.8 (RXDV)
/SDCK: U1.31 (SD_CLK)
/SDCS: U1.30 (SD_CMD)
/SDD0: U1.32 (SD_DATA_0)
/SDD1: U1.33 (SD_DATA_1)
/SDD2: U1.28 (SD_DATA_2)
/SDD3: U1.29 (SD_DATA_3)
/SWO: D1.2 (A), L4.1, L5.1, U2.18 (SWO)
/S_VN: J23.1, U1.8 (SENSOR_VN)
/S_VP: J26.1, U1.5 (SENSOR_VP)
/U0RXD: J18.1, R22.1
/U0TXD: J17.1, R4.1
/VDD3P3: L1.1, U1.3 (VDD3P3), U1.4 (VDD3P3)
/VDD_SDIO: C14.2, R2.2, U1.26 (VDD_SDIO)
/VIN_NEG: J29.1, R20.2, U2.1 (ISNS), U2.8 (HSO)
/VSS: C4.2, C6.2, C7.2, C20.2, C27.2, C28.2, R20.1, U2.4 (FBL), U2.19 (VSS)
/XTAL_N: C12.1, U1.44 (XTAL_N), Y1.1
/XTAL_P: C13.1, U1.45 (XTAL_P), Y1.3
GND: C2.1, C3.1, C5.1, C8.1, C9.1, C10.1, C11.1, C12.2, C13.2, C14.1, C15.1, C16.1, C18.2, C19.2, C21.2, C22.2, C23.2, C24.2, C25.2, C26.2, C29.2, D2.2 (A), J1.12 (LEDG_K), J1.14 (LEDY_K), J1.SH (SHIELD), J3.1, J14.1, J16.1, J27.1, L4.2, L5.2, R2.1, R3.1, R8.1, R11.2, R12.2, R24.1, R27.1, R28.1, SW1.1, U1.49 (GND), U3.2 (GND), U4.31 (CKXTAL1), U4.33 (GND), Y1.2, Y1.4
unnamed: C6.1, R21.1
unnamed: C17.2, D2.1 (K), L2.1, U3.6 (SW)
unnamed: D3.1 (K), R28.2
unnamed: R22.2, U1.40 (U0RXD)
unnamed: R4.2, U1.41 (U0TXD)
unnamed: R7.2, U2.9 (RCLASS)
unnamed: R6.2, U2.6 (RDET)
unnamed: R19.2, U2.10 (RFREQ)
unnamed: C20.1, U2.5 (VDD)
unnamed: C17.1, U3.1 (CB)
unnamed: R26.1, R27.2, U3.3 (FB)

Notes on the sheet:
3.3V
IO0: PU IO2: PD IO4: PD IO5: PU IO12: PD IO15: PU
QFN48 5x5
50MHz 30ppm
https://www.skyworksinc.com/-/media/SkyWorks/SL/documents/public/application-notes/an1130-si3404-06x-dg.pdf https://www.skyworksinc.com/-/media/Skyworks/SL/documents/public/user-guides/ug326-si3406fbc2evb.pdf
OPT
Keep RSET away from other clock sources
12V
Derived from: https://www.espressif.com/sites/default/files/documentation/esp32-wroom-32_datasheet_en.pdf https://www.espressif.com/sites/default/files/documentation/esp32_hardware_design_guidelines_en.pdf https://github.com/LilyGO/ESP32-TTGO-T1/blob/master/T1_V1.3.pdf https://github.com/LilyGO/TTG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
I=500mA
RDET: 24.3k : Silicon Bridge 24.9k : Schottky Brdige
Vsw=380mV
Integrated TVS Diode
>25mil
-12V
Ceramic caps should be X5R or X7R Diode should be fast recovery type f_sw = 550kHz
WiFi/BT not used.
+12V OUT
GPIO16/17 is used for internal flash
20mil
NOTE: Ripple 5V pk-pk for L=10uH !!
[R1]
DNP: Do Not Populate OPT: Optional
[RComp]
C386152
NOTE: There are two variants of U4WDH, single-core & dual-core They have the same part number.
NOTE: CT Must NOT be connected directly to 3.3V (causes stability issues with some switches)
Series termination resistors required on TX from PHY and CLK for stability
Ceramic capacitors should be X5R
Imax = 600mA
Imax=600mA (2W)
NOTE: Type 2 / Class 4 / 20W not supported for Si3404.
PCB Module Footprint
RC delay
[R2]
RXD1: Function [0=LED 1=WOL]
RSENSE: Class 1 / 2R Class 2 / 1.2R Class 3 / 0.62R
INTB: RMII interrupt
RCLASS: Class 0 : OC : 13W Class 1 : 140R : 4W Class 2 : 75R : 6.5W Class 3 : 48.7R : 13W
FLASH_CS

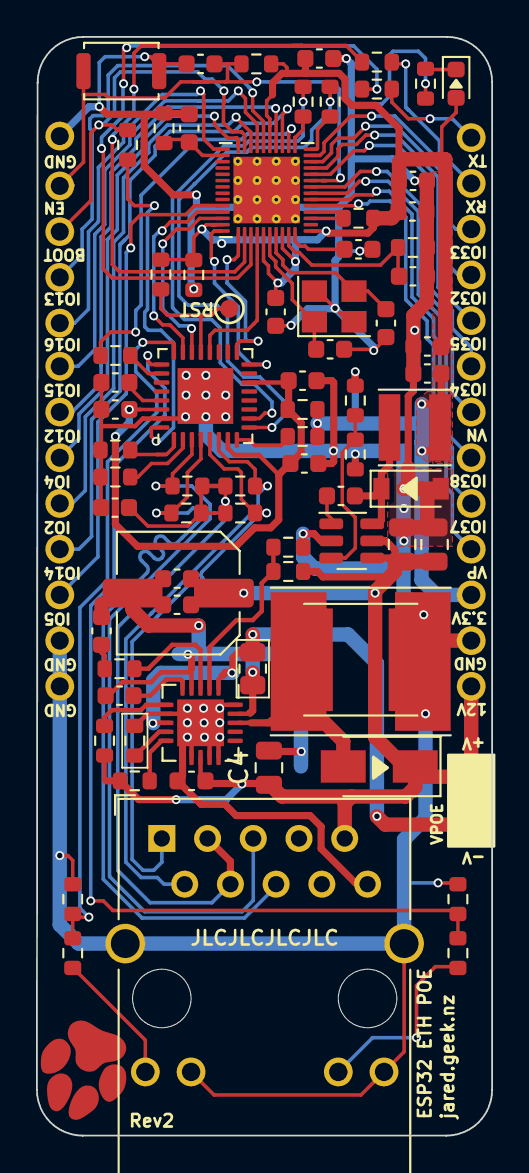
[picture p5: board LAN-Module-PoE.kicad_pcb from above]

Board: 2 copper layers, 25.3 x 61.0 mm, 104 parts (0 on the bottom side), 73 nets.

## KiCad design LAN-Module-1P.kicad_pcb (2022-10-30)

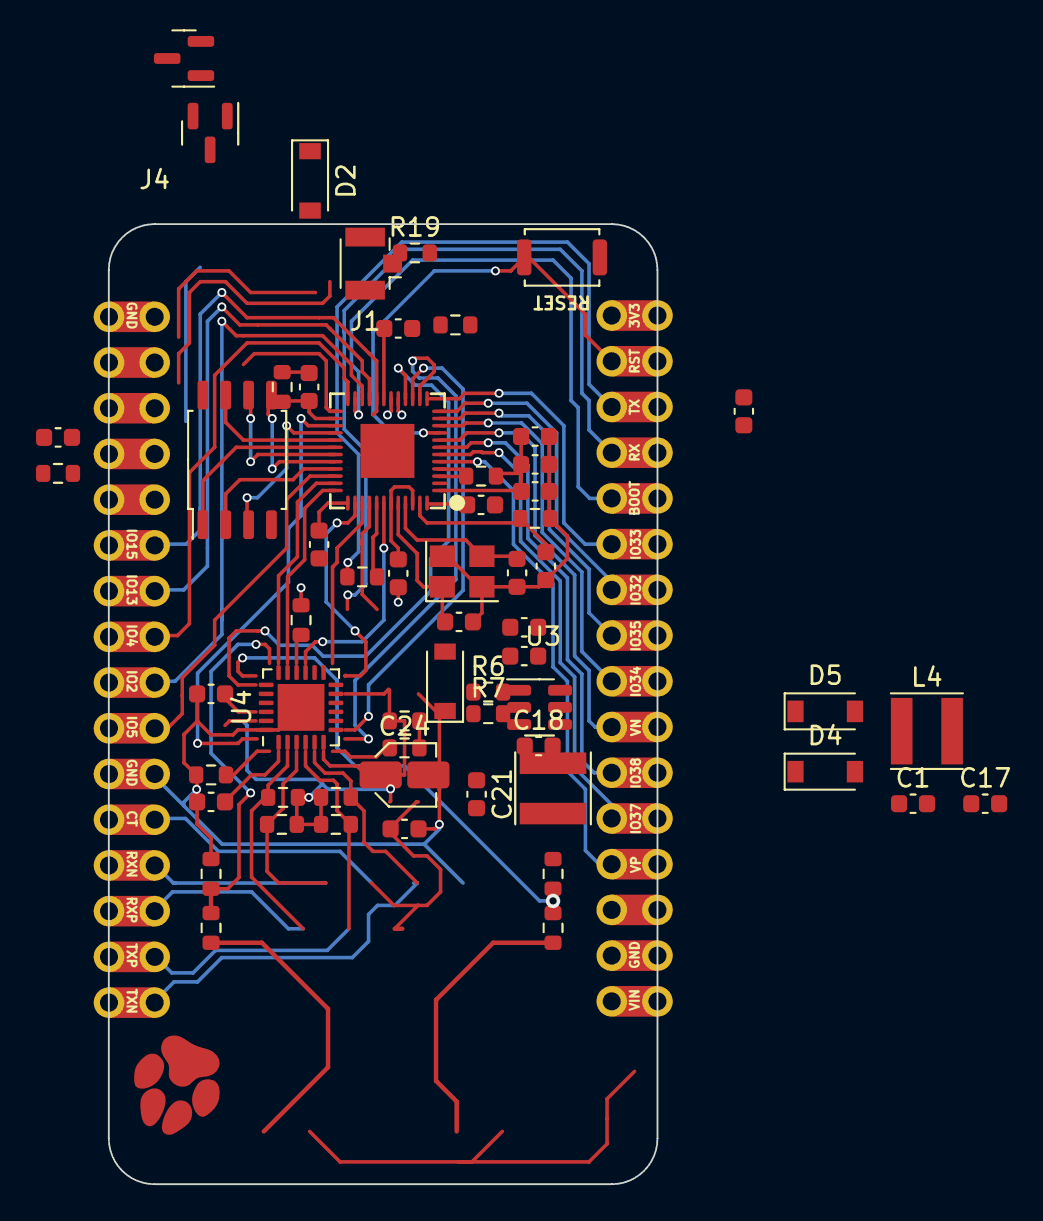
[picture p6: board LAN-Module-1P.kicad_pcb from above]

Board: 2 copper layers, 30.5 x 53.3 mm, 62 parts (0 on the bottom side), 50 nets.

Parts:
C1, C5, C6, C7, C17, C19, C22, C23: 100n; C_0603_1608Metric
C2, C8, C9: 1u; C_0603_1608Metric
C3, C4: 10u; C_0603_1608Metric
C10, C11: 22p; C_0603_1608Metric
C12: 4.7u; C_0603_1608Metric
C13, C15: 3.3n; C_0603_1608Metric
C14, C16: 10n; C_0603_1608Metric
C18, C21: 2.2u; C_0603_1608Metric
C24: 4.7u; C_Elec_3x5.4
D1, D2, D4, D5: FM240W; D_SOD-123
J1: ANT; U.FL_Hirose_U.FL-R-SMT-1_Vertical
J4: Conn_Left; ProtoCastellatedHeader_1x16
J5: Conn_Right; ProtoCastellatedHeader_1x16
L1, L3: FB 600R@100MHz 1.3A; R_0603_1608Metric
L2, L4: 10uH 1A; L_Taiyo-Yuden_NR-40xx
LOGO1: Logo; wolfpaw-0.3
Q1, Q2: 2N7002; SOT-23
R1, R5, R6, R10, R11, R12, R15: 10k; R_0603_1608Metric
R2: 2k; R_0603_1608Metric
R3: 20K; R_0603_1608Metric
R4: 2.49k 1%; R_0603_1608Metric
R7, R8: 499R; R_0603_1608Metric
R9: 10K; R_0603_1608Metric
R13: 22k; R_0603_1608Metric
R14: 47k; R_0603_1608Metric
R16: 33k 1%; R_0603_1608Metric
R17: 10k 1%; R_0603_1608Metric
R18, R19: 0R; R_0603_1608Metric
SW1: RESET; SW_Push_SPST_NO_Alps_SKRK
U1: ESP32-U4WDH; ESP32-REDUCED
U2: W25Q32; SOIC-8_5.23x5.23mm_P1.27mm
U3: LV2842XLVDDCR; SOT-23-6
U4: CP2102N-Axx-xQFN24; QFN-24-1EP_4x4mm_P0.5mm_EP2.6x2.6mm
Y1: 40MHz ±10ppm; Crystal_SMD_3225-4Pin_3.2x2.5mm

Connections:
+3V3: C1.2, C2.2, C3.2, C4.2, C5.2, C6.2, C7.2, C9.2, C17.1, C19.1, C22.2, C24.1, L1.2, L2.2, L4.2, R1.2, R9.2, R15.2, R16.1, U1.1 (VDDA), U1.19 (VDD3P3_RTC), U1.37 (VDD3P3_CPU), U1.43 (VDDA), U1.46 (VDDA), U2.8 (VCC), U4.5 (VIO), U4.6 (VDD), U4.7 (VREGIN)
/BOOT: J5.5, R18.2, U1.23 (GPIO0)
/CAP1: C14.2, C16.2, U1.48 (CAP1)
/CAP2: C13.2, C15.2, R3.2, U1.47 (CAP2)
/EN: C8.2, J5.2, R1.1, R19.2, SW1.2, U1.9 (CHIP_PU)
/ETH_RST: R6.2, R10.2
/IO2: J4.9, U1.22 (GPIO2)
/IO4: J4.8, U1.24 (GPIO4)
/IO5: J4.10, U1.34 (GPIO5)
/IO12: J4.3, R9.1, U1.18 (MTDI)
/IO13: J4.6, U1.20 (MTCK)
/IO14: J4.4, U1.17 (MTMS)
/IO15: J4.7, U1.21 (MTDO)
/IO16: J4.2, U1.25 (GPIO16)
/IO32: J5.7, U1.12 (32K_XP)
/IO33: J5.6, U1.13 (32K_XIN)
/IO34: J5.9, U1.10 (VDET_1)
/IO35: J5.8, U1.11 (VDET_2)
/IO37: J5.12, U1.6 (SENSOR_CAPP)
/IO38: J5.11, U1.7 (SENSOR_CAPN)
/SDCK: U1.31 (SD_CLK), U2.6 (CLK)
/SDCS: U1.30 (SD_CMD), U2.1 (~CS)
/SDD0: U1.32 (SD_DATA_0), U2.5 (DI(IO0))
/SDD1: U1.33 (SD_DATA_1), U2.2 (DO(IO1))
/SDD2: U1.28 (SD_DATA_2), U2.3 (IO2)
/SDD3: U1.29 (SD_DATA_3), U2.7 (IO3)
/S_VN: J5.10, U1.8 (SENSOR_VN)
/S_VP: J5.13, U1.5 (SENSOR_VP)
/U0RXD: J5.4, R7.1, U4.21 (TXD)
/U0TXD: J5.3, R8.1, U4.20 (RXD)
/VDD3P3: L1.1, U1.3 (VDD3P3), U1.4 (VDD3P3)
/VDD_SDIO: C12.2, R2.2, U1.26 (VDD_SDIO)
/XTAL_N: C10.1, U1.44 (XTAL_N), Y1.1
/XTAL_P: C11.1, U1.45 (XTAL_P), Y1.3
GND: C1.1, C2.1, C3.1, C4.1, C5.1, C6.1, C7.1, C8.1, C9.1, C10.2, C11.2, C12.1, C13.1, C14.1, C15.1, C16.1, C17.2, C18.2, C19.2, C21.2, C22.1, C24.2, D1.2 (A), D5.2 (A), J1.2 (Ext), J4.1, J4.11, J5.15, R2.1, R3.1, R4.1, R11.2, R12.2, R14.1, R17.2, SW1.1, U1.49 (GND), U2.4 (GND), U3.2 (GND), U4.2 (GND), U4.25 (GND), Y1.2, Y1.4
unnamed: D1.1 (K), L2.1
unnamed: C23.1, U3.1 (CB)
unnamed: C23.2, D5.1 (K), L4.1, U3.6 (SW)
unnamed: J1.1 (In), U1.2 (LNA_IN)
unnamed: Q1.1 (G), Q2.2 (S), U4.19 (~RTS)
unnamed: Q1.2 (S), R18.1
unnamed: Q1.3 (D), Q2.1 (G), U4.23 (~DTR)
unnamed: Q2.3 (D), R19.1
unnamed: R7.2, U1.40 (U0RXD)
unnamed: R8.2, U1.41 (U0TXD)
unnamed: R13.1, R14.2, U4.8 (VBUS)
unnamed: R15.1, U4.9 (~RST)
unnamed: R16.2, R17.1, U3.3 (FB)
VBUS: D2.2 (A), D4.2 (A), R13.2
VDD: C18.1, C21.1, D2.1 (K), D4.1 (K), L3.1, R5.1, R6.1, R10.1, U3.4 (~SHDN), U3.5 (VIN)

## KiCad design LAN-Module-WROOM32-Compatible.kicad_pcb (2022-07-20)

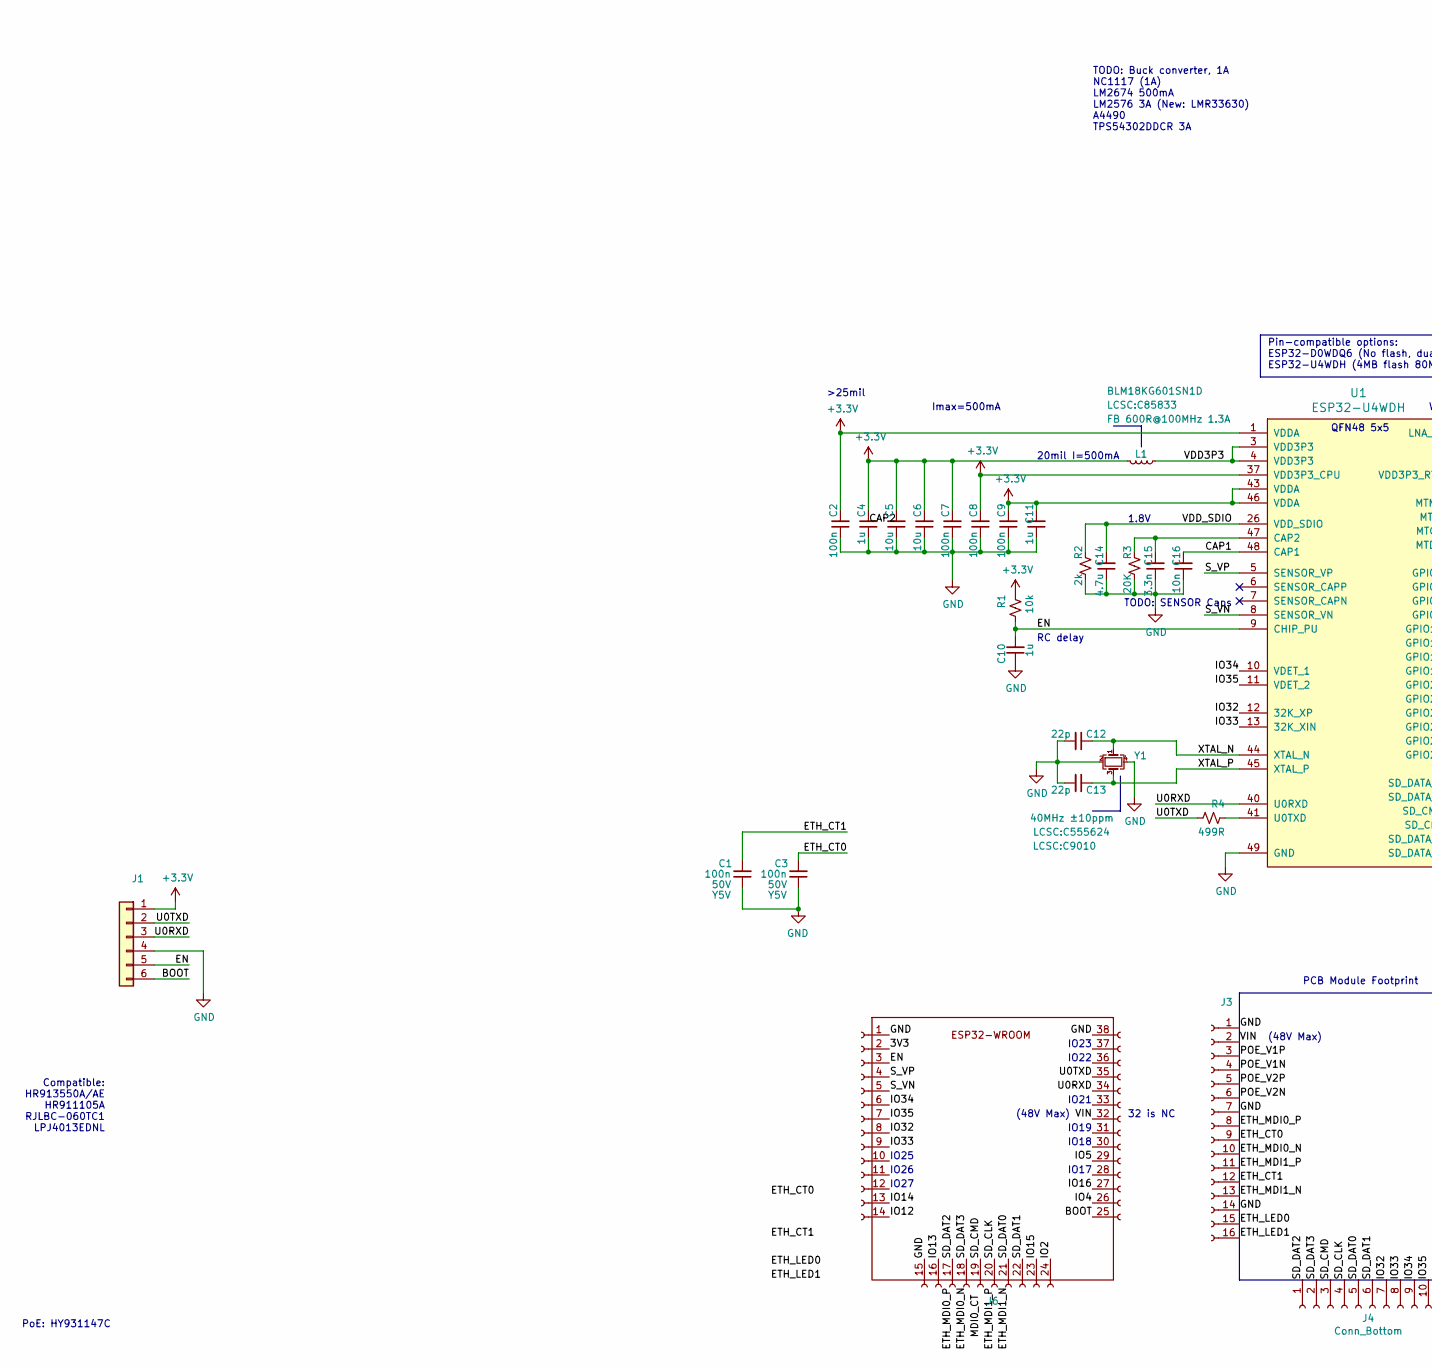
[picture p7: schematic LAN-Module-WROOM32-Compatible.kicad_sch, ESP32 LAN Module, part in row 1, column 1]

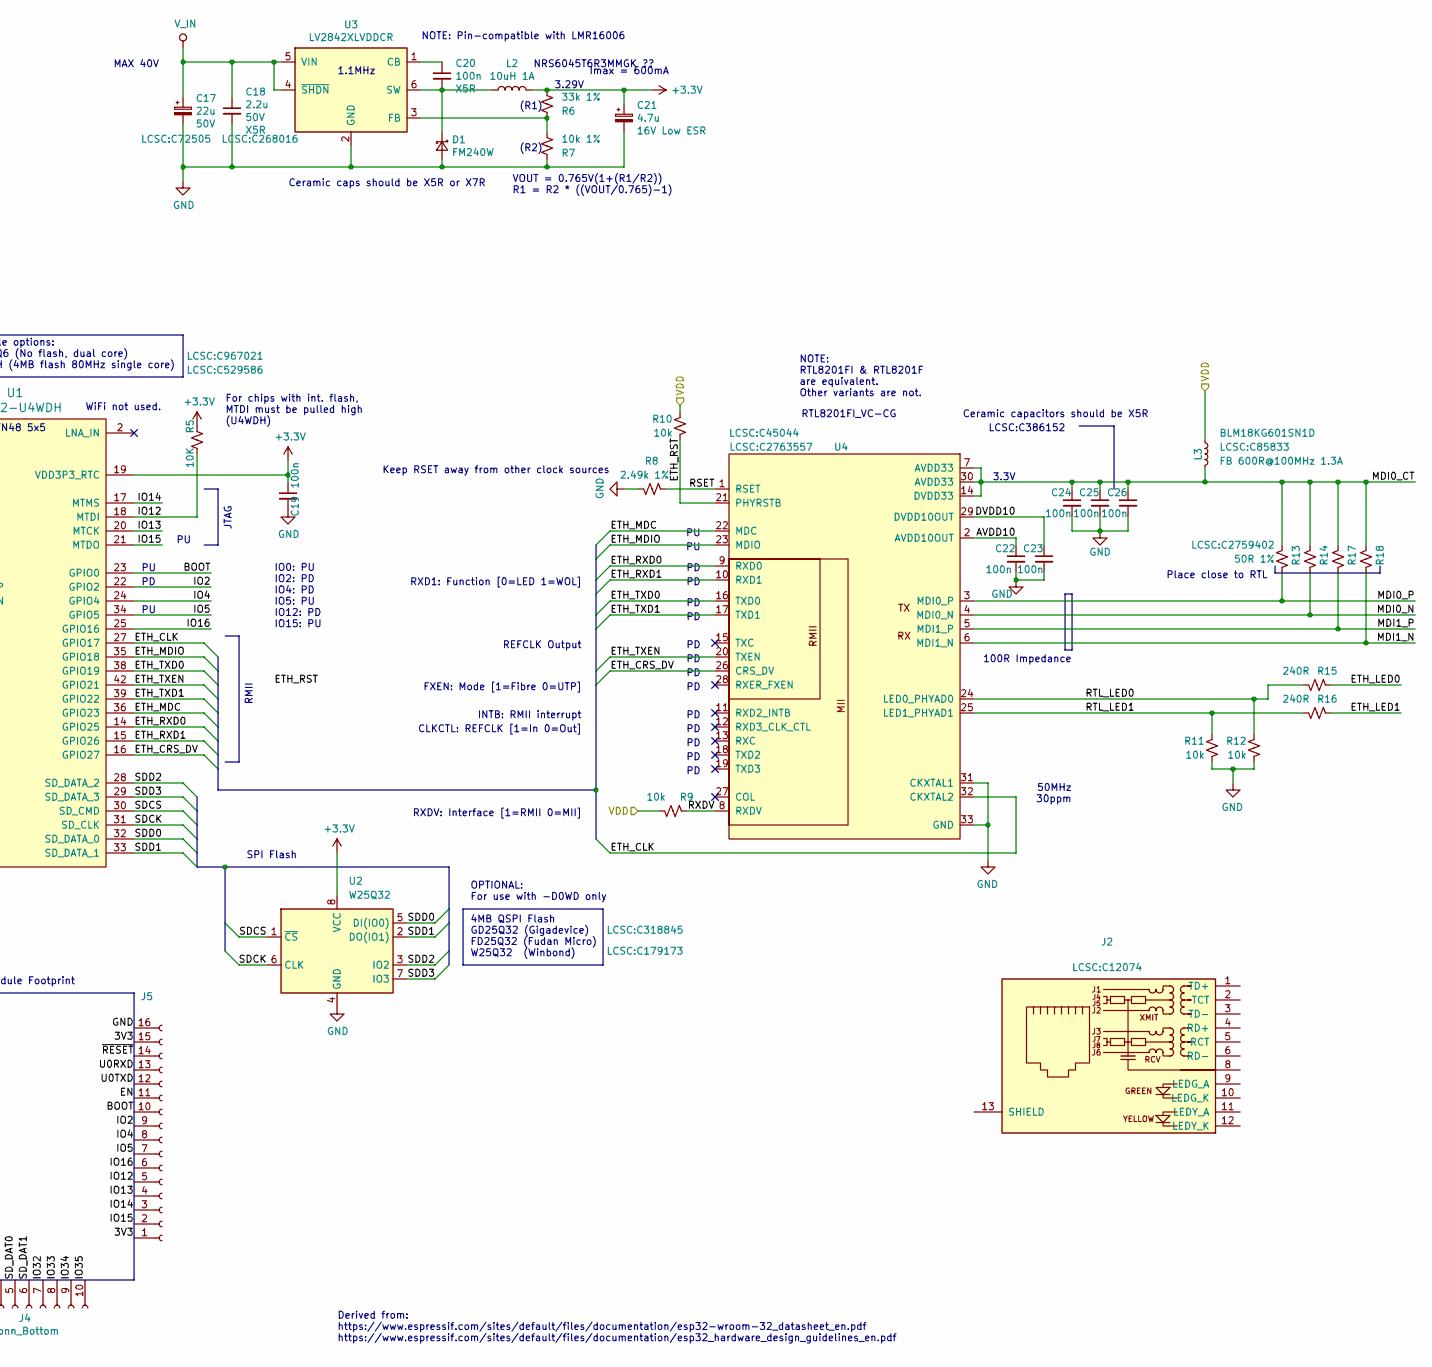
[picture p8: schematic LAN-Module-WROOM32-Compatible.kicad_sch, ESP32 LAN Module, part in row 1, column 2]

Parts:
C1, C3: 100n; C_0603_1608Metric; Rating 50V
C2, C7, C8, C9, C19, C20, C22, C23, C24, C25, C26: 100n; C_0603_1608Metric
C4, C10, C11: 1u; C_0805_2012Metric
C5, C6: 10u; C_Elec_3x5.4
C12, C13: 22p; C_0603_1608Metric
C14, C21: 4.7u; C_Elec_3x5.4
C15: 3.3n; C_0603_1608Metric
C16: 10n; C_0603_1608Metric
C17: 22u; C_Elec_6.3x5.4; Part1 LCSC:C72505
C18: 2.2u; C_0603_1608Metric; Part1 LCSC:C268016
D1: FM240W; D_SMA
J1, J3, J5, J6: (no value)
J2: Part LCSC:C12074
J4: Conn_Bottom
L1, L3: FB 600R@100MHz 1.3A; R_0805_2012Metric_Pad1.20x1.40mm_HandSolder; Part1 LCSC:C85833
L2: 10uH 1A; L_Taiyo-Yuden_NR-40xx
R1, R9, R10, R11, R12: 10k; R_0603_1608Metric
R2: 2k; R_0603_1608Metric
R3: 20K; R_0603_1608Metric
R4: 499R; R_0603_1608Metric
R5: 10K; R_0603_1608Metric
R6: 33k 1%; R_0603_1608Metric
R7: 10k 1%; R_0603_1608Metric
R8: 2.49k 1%; R_0603_1608Metric
R13: 50R 1%; R_0603_1608Metric; Part LCSC:C2759402
R14, R17, R18: 49.9R 1%; R_0603_1608Metric
R15, R16: 240R; R_0603_1608Metric
U1: ESP32-U4WDH; ESP32-REDUCED; Part1 LCSC:C529586
U2: W25Q32; SOIC-8_5.23x5.23mm_P1.27mm; Part LCSC:C179173
U3: LV2842XLVDDCR; SOT-23-6
U4: Part1 LCSC:C2763557
Y1: 40MHz ±10ppm; Crystal_SMD_3225-4Pin_3.2x2.5mm_HandSoldering; Part1 LCSC:C9010

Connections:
+3V3: C2.2, C4.2, C5.2, C6.2, C7.2, C8.2, C9.2, C11.2, C19.1, C21.1, J1.1, L1.2, L2.2, R1.2, R5.2, R6.1, U1.1 (VDDA), U1.19 (VDD3P3_RTC), U1.37 (VDD3P3_CPU), U1.43 (VDDA), U1.46 (VDDA), U2.8 (VCC)
/3V3: J5.1, J5.15, J6.2
/AVDD10: C22.1, U4.2 (AVDD10OUT)
/BOOT: J1.6, J5.10, J6.25, U1.23 (GPIO0)
/CAP1: C16.2, U1.48 (CAP1)
/DVDD10: C23.1, U4.29 (DVDD10OUT)
/EN: C10.2, J1.5, J5.11, J6.3, R1.1, U1.9 (CHIP_PU)
/ETH_CLK: U1.27 (GPIO17), U4.32 (CKXTAL2)
/ETH_CRS_DV: U1.16 (GPIO27), U4.26 (CRS_DV)
/ETH_CT0: C3.2, J3.9
/ETH_CT1: C1.2, J3.12
/ETH_LED0: J3.15, R15.2
/ETH_LED1: J3.16, R16.2
/ETH_MDC: U1.36 (GPIO23), U4.22 (MDC)
/ETH_MDI0_N: J3.10
/ETH_MDI0_P: J3.8
/ETH_MDI1_N: J3.13
/ETH_MDI1_P: J3.11
/ETH_MDIO: U1.35 (GPIO18), U4.23 (MDIO)
/ETH_RST: R10.2, U4.21 (PHYRSTB)
/ETH_RXD0: U1.14 (GPIO25), U4.9 (RXD0)
/ETH_RXD1: U1.15 (GPIO26), U4.10 (RXD1)
/ETH_TXD0: U1.38 (GPIO19), U4.16 (TXD0)
/ETH_TXD1: U1.39 (GPIO22), U4.17 (TXD1)
/ETH_TXEN: U1.42 (GPIO21), U4.20 (TXEN)
/IO2: J5.9, J6.24, U1.22 (GPIO2)
/IO4: J5.8, J6.26, U1.24 (GPIO4)
/IO5: J5.7, J6.29, U1.34 (GPIO5)
/IO12: J5.5, J6.14, R5.1, U1.18 (MTDI)
/IO13: J5.4, J6.16, U1.20 (MTCK)
/IO14: J5.3, J6.13, U1.17 (MTMS)
/IO15: J5.2, J6.23, U1.21 (MTDO)
/IO16: J5.6, J6.27, U1.25 (GPIO16)
/IO32: J4.7, J6.8, U1.12 (32K_XP)
/IO33: J4.8, J6.9, U1.13 (32K_XIN)
/IO34: J4.9, J6.6, U1.10 (VDET_1)
/IO35: J4.10, J6.7, U1.11 (VDET_2)
/MDI0_CT: C24.1, C25.1, C26.1, L3.2, R13.1, R14.1, R17.1, R18.1, U4.7 (AVDD33), U4.14 (DVDD33), U4.30 (AVDD33)
/MDI0_N: R14.2, U4.4 (MDI0_N)
/MDI0_P: R13.2, U4.3 (MDI0_P)
/MDI1_N: R18.2, U4.6 (MDI1_N)
/MDI1_P: R17.2, U4.5 (MDI1_P)
/POE_V1N: J3.4
/POE_V1P: J3.3
/POE_V2N: J3.6
/POE_V2P: J3.5
/RSET: R8.2, U4.1 (RSET)
/RTL_LED0: R12.1, R15.1, U4.24 (LED0_PHYAD0)
/RTL_LED1: R11.1, R16.1, U4.25 (LED1_PHYAD1)
/RXDV: R9.2, U4.8 (RXDV)
/SDCK: U1.31 (SD_CLK), U2.6 (CLK)
/SDCS: U1.30 (SD_CMD), U2.1 (~CS)
/SDD0: U1.32 (SD_DATA_0), U2.5 (DI(IO0))
/SDD1: U1.33 (SD_DATA_1), U2.2 (DO(IO1))
/SDD2: U1.28 (SD_DATA_2), U2.3 (IO2)
/SDD3: U1.29 (SD_DATA_3), U2.7 (IO3)
/SD_CLK: J4.4, J6.20
/SD_CMD: J4.3, J6.19
/SD_DAT0: J4.5, J6.21
/SD_DAT1: J4.6, J6.22
/SD_DAT2: J4.1, J6.17
/SD_DAT3: J4.2, J6.18
/S_VN: J6.5, U1.8 (SENSOR_VN)
/S_VP: J6.4, U1.5 (SENSOR_VP)
/U0RXD: J1.3, J5.13, J6.34, U1.40 (U0RXD)
/U0TXD: J1.2, J5.12, J6.35, R4.1
/VDD3P3: L1.1, U1.3 (VDD3P3), U1.4 (VDD3P3)
/VDD_SDIO: C14.2, R2.2, U1.26 (VDD_SDIO)
/VIN: J3.2, J6.32
/XTAL_N: C12.1, U1.44 (XTAL_N), Y1.1
/XTAL_P: C13.1, U1.45 (XTAL_P), Y1.3
/~RESET: J5.14
GND: C1.1, C2.1, C3.1, C4.1, C5.1, C6.1, C7.1, C8.1, C9.1, C10.1, C11.1, C12.2, C13.2, C14.1, C15.1, C16.1, C17.2, C18.2, C19.2, C21.2, C22.2, C23.2, C24.2, C25.2, C26.2, D1.2 (A), J1.4, J3.1, J3.7, J3.14, J5.16, J6.1, J6.15, J6.38, R2.1, R3.1, R7.2, R8.1, R11.2, R12.2, U1.49 (GND), U2.4 (GND), U3.2 (GND), U4.31 (CKXTAL1), U4.33 (GND), Y1.2, Y1.4
unnamed: C15.2, R3.2, U1.47 (CAP2)
unnamed: C20.1, U3.1 (CB)
unnamed: C20.2, D1.1 (K), L2.1, U3.6 (SW)
unnamed: R4.2, U1.41 (U0TXD)
unnamed: R6.2, R7.1, U3.3 (FB)
VDD: C17.1, C18.1, L3.1, R9.1, R10.1, U3.4 (~SHDN), U3.5 (VIN)

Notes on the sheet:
IO17
1.8V
TODO: SENSOR Caps
IO0: PU IO2: PD IO4: PD IO5: PU IO12: PD IO15: PU
IO23
QFN48 5x5
1.1MHz
50MHz 30ppm
IO18
Keep RSET away from other clock sources
Derived from: https://www.espressif.com/sites/default/files/documentation/esp32-wroom-32_datasheet_en.pdf https://www.espressif.com/sites/default/files/documentation/esp32_hardware_design_guidelines_en.pdf
I=500mA
IO26
OPTIONAL: For use with -D0WD only 4MB QSPI Flash GD25Q32 (Gigadevice) FD25Q32 (Fudan Micro) W25Q32 (Winbond)
IO19
TODO: Buck converter, 1A NC1117 (1A) LM2674 500mA LM2576 3A (New: LMR33630) A4490 TPS54302DDCR 3A
>25mil
NRS6045T6R3MMGK ??
MAX 40V
(48V Max)
WiFi not used.
VOUT = 0.765V(1+(R1/R2)) R1 = R2 * ((VOUT/0.765)-1)
(R1)
20mil
Imax = 600mA
32 is NC
LCSC:C386152
PoE: HY931147C
Ceramic caps should be X5R or X7R
Compatible: HR913550A/AE HR911105A RJLBC-060TC1 LPJ4013EDNL
3.3V
Pin-compatible options: ESP32-D0WDQ6 (No flash, dual core) ESP32-U4WDH (4MB flash 80MHz single core)
Ceramic capacitors should be X5R
PCB Module Footprint
RC delay
RXD1: Function [0=LED 1=WOL]
IO27
NOTE: Pin-compatible with LMR16006
INTB: RMII interrupt
JTAG

Board: 2 copper layers, 57 parts (0 on the bottom side), 64 nets, no tracks yet.

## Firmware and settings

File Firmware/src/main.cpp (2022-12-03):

#define LOG_LOCAL_LEVEL ESP_LOG_VERBOSE
#include "esp_log.h"

#include <Arduino.h>

// #ifndef ETH_ADDR
//     #define ETH_ADDR        0
//     #define ETH_POWER_PIN   -1
//     #define ETH_MDC_PIN     23
//     #define ETH_MDIO_PIN    18
//     #define ETH_TYPE        ETH_PHY_RTL8201
//     #define ETH_CLK_MODE    ETH_CLOCK_GPIO17_OUT
// #endif

#include <ETH.h>

static volatile bool eth_link_up = false;

static void eth_event_handler(void *arg, esp_event_base_t event_base,
                              int32_t event_id, void *event_data)
{
    uint8_t mac_addr[6] = {0};

    /* we can get the ethernet driver handle from event data */
    esp_eth_handle_t eth_handle = *(esp_eth_handle_t *)event_data;

    switch (event_id) {
    case ETHERNET_EVENT_CONNECTED:
        esp_eth_ioctl(eth_handle, ETH_CMD_G_MAC_ADDR, mac_addr);
        Serial.println("Ethernet Link Up");
        Serial.printf("Ethernet HW Addr %02x:%02x:%02x:%02x:%02x:%02x\n",
                    mac_addr[0], mac_addr[1], mac_addr[2], mac_addr[3], mac_addr[4], mac_addr[5]);
        eth_link_up = true;
        break;
    case ETHERNET_EVENT_DISCONNECTED:
        Serial.println("Ethernet Link Down");
        eth_link_up = false;
        break;
    case ETHERNET_EVENT_START:
        Serial.println("Ethernet Started");
        break;
    case ETHERNET_EVENT_STOP:
        Serial.println("Ethernet Stopped");
        break;
    default:
        break;
    }
}

/** Event handler for IP_EVENT_ETH_GOT_IP */
static void got_ip_event_handler(void *arg, esp_event_base_t event_base,
                                 int32_t event_id, void *event_data)
{
    switch (event_id) 
    {
        case IP_EVENT_STA_GOT_IP: Serial.println("IP_EVENT_STA_GOT_IP");               /*!< station got IP from connected AP */
        case IP_EVENT_STA_LOST_IP: Serial.println("IP_EVENT_STA_LOST_IP");              /*!< station lost IP and the IP is reset to 0 */
        case IP_EVENT_AP_STAIPASSIGNED: Serial.println("IP_EVENT_AP_STAIPASSIGNED");         /*!< soft-AP assign an IP to a connected station */
        case IP_EVENT_GOT_IP6: Serial.println("IP_EVENT_GOT_IP6");                  /*!< station or ap or ethernet interface v6IP addr is preferred */
        case IP_EVENT_ETH_GOT_IP: Serial.println("IP_EVENT_ETH_GOT_IP");               /*!< ethernet got IP from connected AP */
        case IP_EVENT_ETH_LOST_IP: Serial.println("IP_EVENT_ETH_LOST_IP");              /*!< ethernet lost IP and the IP is reset to 0 */
        case IP_EVENT_PPP_GOT_IP: Serial.println("IP_EVENT_PPP_GOT_IP");               /*!< PPP interface got IP */
        case IP_EVENT_PPP_LOST_IP: Serial.println("IP_EVENT_PPP_LOST_IP");              /*!< PPP interface lost IP */

    }

    if (event_id == IP_EVENT_ETH_GOT_IP) {
        ip_event_got_ip_t *event = (ip_event_got_ip_t *) event_data;
        const esp_netif_ip_info_t *ip_info = &event->ip_info;

        Serial.println("Ethernet Got IP Address");
        Serial.printf("ETHIP:" IPSTR "\n", IP2STR(&ip_info->ip));
        Serial.printf("ETHMASK:" IPSTR "\n", IP2STR(&ip_info->netmask));
        Serial.printf("ETHGW:" IPSTR "\n", IP2STR(&ip_info->gw));
    }
}

void setup() {
    Serial.begin(115200);
    Serial.println("Connecting LAN");

    WiFi.mode(WIFI_OFF); 

    //delay(1000);

    esp_log_level_set("*", ESP_LOG_VERBOSE);
    esp_log_level_set("wifi", ESP_LOG_VERBOSE);
    esp_log_level_set("eth", ESP_LOG_VERBOSE);
    esp_log_level_set("dhcpc", ESP_LOG_VERBOSE);   

    //ETH.config(INADDR_NONE, INADDR_NONE, INADDR_NONE, INADDR_NONE);

    esp_netif_init();
    esp_event_loop_create_default(); // create a default event loop that running in background
    esp_event_handler_register(ETH_EVENT, ESP_EVENT_ANY_ID, &eth_event_handler, NULL); // register Ethernet event handler
    esp_event_handler_register(IP_EVENT, ESP_EVENT_ANY_ID, &got_ip_event_handler, NULL);

    //while (!ETH.begin(ETH_ADDR, ETH_POWER_PIN, ETH_MDC_PIN, ETH_MDIO_PIN, ETH_TYPE))
    while (!ETH.begin())
    {
        Serial.print(".");
    }

    ETH.config(INADDR_NONE, INADDR_NONE, INADDR_NONE);
    ETH.setHostname("esp32");

    //ETH.begin();
    
    //while (!ETH.linkUp())
    while (!eth_link_up)
    {
        Serial.print(".");
        delay(1000);
    }

    Serial.print("IP address: ");
    Serial.println(ETH.localIP());

    Serial.print("Gateway:    ");
    Serial.println(ETH.gatewayIP());
}

void loop() {

}

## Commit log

2022-09-16 Layout PCB
    [LAN-Module.kicad_pcb, LAN-Module.kicad_sch]
2022-10-29 Final routing and placement
    [LAN-Module.kicad_pcb, LAN-Module.kicad_sch]
2022-10-30 Address TODOs
    [LAN-Module.kicad_pcb, LAN-Module.kicad_sch]
2022-10-30 Generate gerbers r1
    [LAN-Module-B_Cu.gbl, LAN-Module-B_Mask.gbs, LAN-Module-B_Silkscreen.gbo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]
2022-10-30 Add PoE variant
    [LAN-Module-PoE.kicad_pcb, LAN-Module-PoE.kicad_sch]
2022-10-30 Add 1Pair Ethernet Variant (WIP)
    [LAN-Module-1P.kicad_pcb, LAN-Module-1P.kicad_sch]
2022-11-09 Final revision of PoE variant
    [LAN-Module-PoE-B_Cu.gbl, LAN-Module-PoE-B_Mask.gbs, LAN-Module-PoE-B_Silkscreen.gbo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]
2022-11-18 Fix footprint for ESP32 (QFN 5x5), add heat pad for PoE regulator
    [LAN-Module-PoE.kicad_pcb, LAN-Module-PoE.kicad_sch]
2022-11-18 Re-layout with narrower board outline (-0.1")
    [LAN-Module-PoE.kicad_pcb]
2022-11-20 Finalize layout for rev2
    [LAN-Module-PoE.kicad_pcb, LAN-Module-PoE.kicad_sch]
2022-12-03 Gerbers for manufacture, rev2
    [LAN-Module-PoE-B_Cu.gbl, LAN-Module-PoE-B_Mask.gbs, LAN-Module-PoE-B_Silkscreen.gbo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]
2022-12-03 Final PoE design with fixes for rev2 gerber spin
    - MTDI must not be pulled high
    - GPIO17 for PHY clock conflicts with internal flash
    [LAN-Module-PoE.kicad_pcb, LAN-Module-PoE.kicad_sch]
2022-12-03 Add sample firmware for ETH-POE
2022-12-04 Update LCSC part numbers and adjust component values to available parts
    [LAN-Module-PoE.kicad_pcb, LAN-Module-PoE.kicad_sch]
2025-02-28 Add sample ESPHome config
2025-02-28 Rev2.1 changes
    Just changing component attributes, no design changes
    [LAN-Module-B_Cu.gbl, LAN-Module-B_Mask.gbs, LAN-Module-B_Silkscreen.gbo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]
2025-02-28 Update kicad project files
2025-02-28 Add variant with castellated holes
    [LAN-Module-PoE-Castellated-B_Cu.gbl, LAN-Module-PoE-Castellated-B_Mask.gbs, LAN-Module-PoE-Castellated-B_Silkscreen.gbo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]
2025-03-16 Update PoE PCB Kicad version
    [LAN-Module-PoE.kicad_pcb]
2025-03-16 HW REV: Fix stability issue
    Important change required to ensure stability across different types of ethernet switches.
    I had only tested this with a TP-LINK switch, but the design did not work with other switches, and the reference schematic does NOT specify that the CT/termination resistors should be tied to 3.3V. Instead they should be coupled to GND through a capacitor (of unspecified value).
    [LAN-Module-PoE-Castellated.kicad_pcb, LAN-Module-PoE-Castellated.kicad_sch, LAN-Module-PoE.kicad_pcb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]
